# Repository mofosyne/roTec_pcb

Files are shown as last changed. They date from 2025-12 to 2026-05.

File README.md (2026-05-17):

# roTec_pcb

<details>
<summary>Revision 5.4 (Though Hole Version)</summary>

| Front (Through Hole Version) | Back (Through Hole Version) |
|:---|:---|
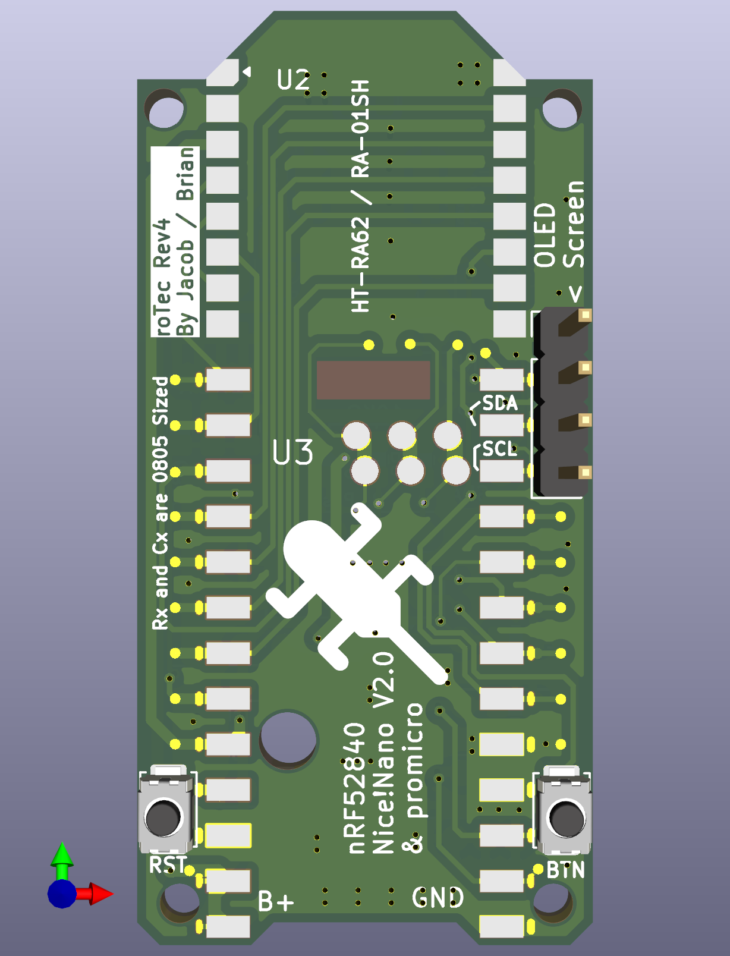
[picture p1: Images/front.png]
Front of PCB
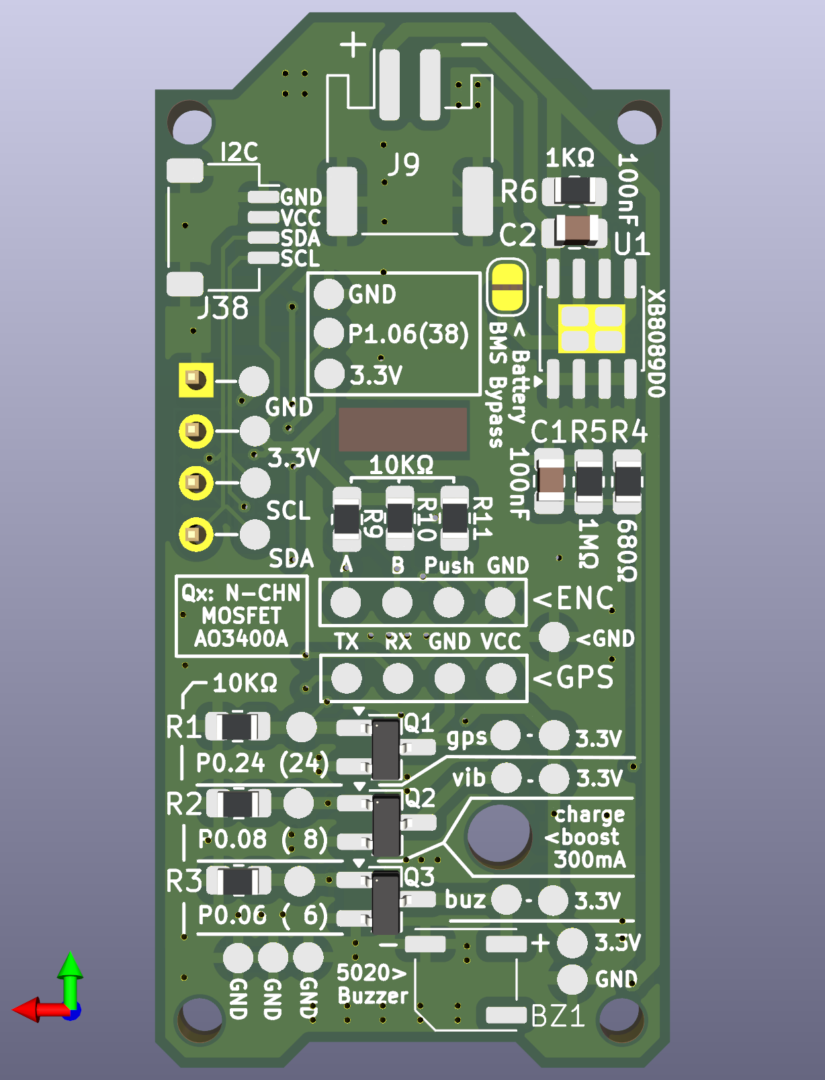
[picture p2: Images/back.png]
Back of PCB
|  |  |

[Release Files For PCB Revision 5.4 (Though Hole Version)](https://github.com/mofosyne/roTec_pcb/releases/tag/rev5.4)

</details>

<details>
<summary>Revision 5.3 (Surface Mount)</summary>

| Front | Back |
|:---|:---|
| Front of PCB | Back of PCB |

[Release Files For PCB Revision 5.3 (All features except for GPS tested) (Recommended)](https://github.com/mofosyne/roTec_pcb/releases/tag/rev5.3)

</details>

RoTec is a low-cost nRF52 device with the form-factor of the Heltec v2, v3, & v4 devices compatible with [Meshtastic](https://meshtastic.org/)®, designed for use with rotary encoders as well as being easy to follow for less technical users.

The history of this design is that it is a fork of [Jacob's](https://github.com/jtljac) fork of the fakeTec.

This design is specifically based off of [Šimon Hořánek's](https://github.com/ShimonHoranek) [fakeTec V5 Rev. B](https://github.com/gargomoma/fakeTec_pcb/issues/24), licensed under [CERN-OHL-P-2.0](https://choosealicense.com/licenses/cern-ohl-p-2.0/).

**[For more meshtastic/meshcore/lora DIY nodes, do check this list out!](https://github.com/porkcube/meshtastic-diy-nodes)**

## Design Documentations (Through Hole Version)



* [Schematic as pdf](./Circuit_Through_Hole/documentation/roTec_schematic.pdf)
* [Schematic Bill Of Materials](./Circuit_Through_Hole/documentation/roTec_bom.csv)

* You may also want to manufacture [EC11 Rotary Encoder Horizontal Breakout Board](https://github.com/mofosyne/kicad_useful_pcbs/tree/main?tab=readme-ov-file#ec11-horizontal-breakout-board), so you can more easily wire the rotary encoder to the roTec via a JST-SH-4 cable.

This has the same parts list as the SMD version, but with a few parts subtracted.

## Design Documentations (Surface Mount Version)



* [Schematic as pdf](./Circuit/documentation/roTec_schematic.pdf)
* [Schematic Bill Of Materials](./Circuit/documentation/roTec_bom.csv)

* You may also want to manufacture [EC11 Rotary Encoder Horizontal Breakout Board](https://github.com/mofosyne/kicad_useful_pcbs/tree/main?tab=readme-ov-file#ec11-horizontal-breakout-board), so you can more easily wire the rotary encoder to the roTec via a JST-SH-4 cable.

### Bill of materials

<details>
<summary>Bill of material. For full details and descriptions refer to the csv BOM above instead.</summary>

| Reference | Value | Qty | Manufacturer | MPN | Package | Datasheet | Manufacturer Parts Link (MPL) | Shopping |
|---|---|-----|---|---|---|---|---|---|
| J9 | Molex PicoBlade 0532610271 | 1 | CJT(Changjiang Connectors) | A1251WR-S-2P | SMD,P=1.25mm,Surface Mount,Right Angle | [datasheet](https://www.molex.com/content/dam/molex/molex-dot-com/products/automated/en-us/salesdrawingpdf/532/53261/532610271_sd.pdf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) | [lcsc](https://www.lcsc.com/product-detail/C225111.html) | [LCSC](https://www.lcsc.com/search?q=0532610271&s_z=n_0532610271) |
| U1 | XB8089D0 BMS | 1 | XySemi | XB8089D0 | SOIC-8 | [datasheet](https://www.lcsc.com/datasheet/lcsc_datasheet_2410121637_XySemi-XB8089D0_C2760005.pdf ) | [lcsc](https://www.lcsc.com/product-detail/C2760005.html?s_z=n_XySemi%2520XB8089D0) | [LCSC](https://www.lcsc.com/search?q=XB8089D0&s_z=n_XB8089D0) |
| Q1,Q2,Q3 | n-chn mosfet | 3 | Alpha & Omega Semiconductor Inc. | AO3400A | SOT-23-3L | [datasheet](http://www.aosmd.com/pdfs/datasheet/AO3400A.pdf ) | [lcsc](https://www.lcsc.com/product-detail/C20917.html?s_z=n_AO3400A) | [LCSC](https://www.lcsc.com/search?q=MOSFET%2520N-CH%2520SOT-23-3L&s_z=n_MOSFET%2520N-CH%2520SOT-23-3L) |
| BZ1 | Buzzer 5020 | 1 | HYDZ | HYG-5020A | SMD,5x5mm | [datasheet](https://www.lcsc.com/datasheet/C7544810.pdf ) | [lcsc](https://www.lcsc.com/product-detail/C7544810.html?s_z=n_buzzer%25205020) | [LCSC](https://www.lcsc.com/search?q=Buzzer_5020&s_z=n_Buzzer_5020) |
| J38,J50 | JST-SH-4 | 2 | JST Sales America Inc. | SM04B-SRSS-TB | SMD,P=1mm,Surface Mount,Right Angle | [datasheet](https://www.jst-mfg.com/product/pdf/eng/eSH.pdf ) | [lcsc](https://www.lcsc.com/product-detail/C51940130.html?s_z=n_SM04B-SRSS-TB) | [LCSC](https://www.lcsc.com/search?q=SM04B-SRSS-TB&s_z=n_SM04B-SRSS-TB) |
| OLED1 | I2C OLED Module | 1 | | | Through Hole | [datasheet](https://cdn-shop.adafruit.com/datasheets/SSD1306.pdf ) | [aliexpress](https://www.aliexpress.com/item/1005008738379315.html) | [aliexpress](https://www.aliexpress.com/w/wholesale-0.96-Inch-OLED-Display-Module.html) |
| U3 | nice!nano v2 | 1 | Nice! | nice!nano v2 | nice!nano v2 | [datasheet](https://nicekeyboards.com/docs/nice-nano/pinout-schematic ) | [aliexpress](https://www.aliexpress.com/item/1005010222966695.html) | [aliexpress](https://www.aliexpress.com/w/wholesale-NRF52840-1%2525252d10PCS.html) |
| SW1 | Reset | 1 | XUNPU | TS-1088R-02026 | SMD,4x3mm | [datasheet](https://www.lcsc.com/datasheet/C455280.pdf ) | [lcsc](https://www.lcsc.com/product-detail/C455280.html?s_z=n_TS-1088R-02026) | [LCSC](https://www.lcsc.com/search?q=TS-1088R-02026&s_z=n_TS-1088R-02026) |
| SW2 | SW_Push | 1 | XUNPU | TS-1088R-02026 | SMD,4x3mm | [datasheet](https://www.lcsc.com/datasheet/C455280.pdf ) | [lcsc](https://www.lcsc.com/product-detail/C455280.html?s_z=n_TS-1088R-02026) | [LCSC](https://www.lcsc.com/search?q=TS-1088R-02026&s_z=n_TS-1088R-02026) |
| R1,R2,R3,R9,R10,R11 | 10k | 6 | | | 0805 | | | [LCSC](https://www.lcsc.com/search?q=10K%25200805&s_z=n_10K%25200805) |
| R4 | 680K | 1 | | | 0805 | | | [LCSC](https://www.lcsc.com/search?q=680K%25200805&s_z=n_680K%25200805) |
| R5 | 1.0M | 1 | | | 0805 | | | [LCSC](https://www.lcsc.com/search?q=1M%25200805&s_z=n_1M%25200805) |
| R6 | 1k | 1 | | | 0805 | | | [LCSC](https://www.lcsc.com/search?q=1k%25200805&s_z=n_1k%25200805) |
| SW3 | RotaryEncoder_Switch | 1 | Same Sky (Formerly CUI Devices)  | ACZ11BR1E-15KQA1-12C | EC11 | [datasheet](https://www.cuidevices.com/product/resource/acz11.pdf ) | [aliexpress](https://www.aliexpress.com/item/1005010398201852.html) or [digikey](https://www.digikey.com.au/en/products/detail/same-sky-formerly-cui-devices/ACZ11BR1E-15KQA1-12C/1923334) | [aliexpress](https://www.aliexpress.com/w/wholesale-rotary-encoder-EC11-horizontal.html) or [digikey](https://www.digikey.com.au/short/7v5m7j9j) |
| U2 | HT-RA62 | 1 | Heltec | HT-RA62 | HT-RA62 | [datasheet](https://resource.heltec.cn/download/HT-RA62/HT-RA62(Rev1.1).pdf ) | [aliexpress](https://www.aliexpress.com/item/1005005543917617.html) | [aliexpress](https://www.aliexpress.com/w/wholesale-HT%2525252dRA62.html) |
| C1,C2 | 100nF | 2 | | | 0805 | | | [LCSC](https://www.lcsc.com/search?q=100nF%25200805&s_z=n_100nF%25200805) |
| M1 | ERM Motor | 1 | Seeed Technology Co., Ltd | 316040001 | Wire Leads | [datasheet](https://mm.digikey.com/Volume0/opasdata/d220001/medias/docus/2234/1020-15-003-001_Spec.pdf ) | [digikey](https://www.digikey.com.au/en/products/detail/seeed-technology-co-ltd/316040001/5487672) | [aliexpress](https://www.digikey.com.au/short/332zpfdb) |

Purchase Tips:
* You can often buy SMD resistor kits in booklets from most places like amazon or aliexpress.
* Both nice!nano and promicro versions are supported
* You can swap the AO3400A n-channel mosfet with other higher current mosfet like SI2312 as long as the pins and packaqe size matches.
* Vibrations motors can be purchased in bulk pretty cheaply in aliexpress, ebay, amazon, etc...
* XB8089D0 BMS can be skipped if your battery have integrated battery protection already
* JST-SH-4 is optional if you want to solder the rotary encoder, gps, or i2c sensors directly onto the solder pads provided on the board instead
* For GPS support you can buy either ATGM336H or GY-GPS6MV2 modules
* Any OLED screen can be used. Pick one that is designed for your case. Often it's an SSD1306 controller based OLED screen.
* Any lora radios seen inside this [reference schematic](https://github.com/meshtastic/firmware/blob/develop/variants/nrf52840/diy/nrf52_promicro_diy_tcxo/Schematic_Pro-micro_Pinouts_2025-12-04.pdf) that fits the footprint and pinout is supported
  - Just like the faketecs you can also use RA-01SH.
* This design supports 3 different battery connectors types
  - Molex Picoblade 2-Pin
    - MPC: Molex, MPN: 0532610271
    - MPC: CJT (Changjiang Connectors), MPN: A1251WR-S-2P
    - Pitch: 1.25mm
    - Used By: HelTec LoRa 32
  - JST PH 2-Pin
    - MPN: S2B-PH-SM4-TB
    - Pitch: 2.00mm 
    - Used By: RAK19007 WisBlock
  - Direct wiring. 
    - e.g. JST-PH-2 but as an external wire like this [aliexpress product](https://www.aliexpress.com/item/1005002564191148.html)

</details>

## Setting Up Device

### Configure

Included in this repository is `roTec_module_config.yaml` which when you run below command will configure the buzzer, vibration motor and encoder.

```
PORT=/dev/ttyACM0 # Set to the serial port of the roTec after flashing
meshtastic --port $PORT --info
meshtastic --port $PORT --configure roTec_module_config.yaml
meshtastic --port $PORT --reboot
```

Alternatively you could manually use the web interface to set the settings using <client.meshtastic.org> as shown below
(No GPS settings it's already enabled by default if the module is installed).

#### Rotary Encoder Settings:

| Settings | Value |
|---|---|
| module_config.cannedMessage.allowInputSource | rotEnc1 |
| module_config.cannedMessage.enabled | true |
| module_config.cannedMessage.inputbrokerEventCcw | RIGHT |
| module_config.cannedMessage.inputbrokerEventCw | LEFT |
| module_config.cannedMessage.inputbrokerEventPress | SELECT  |
| module_config.cannedMessage.inputbrokerPinA | 33 |
| module_config.cannedMessage.inputbrokerPinB | 34 |
| module_config.cannedMessage.inputbrokerPinPress | 39 |
| module_config.cannedMessage.rotary1Enabled | true |

#### Vibration Notification Settings:

| Settings | Value |
|---|---|
| module_config.externalNotification.enabled | true  |
| module_config.externalNotification.alertBell | true  |
| module_config.externalNotification.alertBellVibra | true  |
| module_config.externalNotification.alertMessageVibra | true  |
| module_config.externalNotification.outputVibra | 8 |

#### Buzzer Settings:

**Note you have to override buzzer gpio in config device page**

| Settings | Value |
|---|---|
| config.device.buzzerGpio | 6 |
| module_config.externalNotification.enabled | true |
| module_config.externalNotification.alertBell | true |
| module_config.externalNotification.alertBellBuzzer | true |
| module_config.externalNotification.alertMessageBuzzer | true |
| module_config.externalNotification.outputBuzzer | 6 |
| module_config.externalNotification.usePwm | true |
| ringtone | `24:d=32,o=5,b=565:f6,p,f6,4p,p,f6,p,f6,2p,p,b6,p,b6,p,b6,p,b6,p,b,p,b,p,b,p,b,p,b,p,b,p,b,p,b,1p.,2p.,p` |

## Features
- Small size based on Heltec v3: You can use the same cases!
- Lora with Heltec's HT-RA62
- Uses a [n!cenano](https://nicekeyboards.com/nice-nano/) or 
  [NRF52840 ProMicro](https://github.com/joric/nrfmicro/wiki/Alternatives#supermini-nrf52840l)
- BMS For low voltage cutout to prevent LiPo Overdraining
- Battery level sensing
- JST PH2.0mm connector for batteries
- I2C side ports ready to connect an OLED SSD1306 screen.
- Pads for connecting an encoder for canned messages
- Pads for connecting a serial GPS module
- MOSFETs for switching high current components
  - Using a solder pad jumper, MOSFET 1 can chose between the GPS module ground to enable power saving the GPS module, 
    or a regular pad like MOSFETs 2 & 3.
- 2mm mounting holes

## Modifications from fakeTec V5 Rev. B
- Cleaned up schematic
  - Changed Pins representing sides of MCUs to symbols fully representing said MCU
  - Changed labels to my preferred naming scheme
  - Updated/Cleaned up symbol fields to make each component easier to find
    - MPN: Manufacturer Parts Number
    - MPD: Manufacturer Parts Description
    - MPL: Manufacturer Parts Link
    - Shopping: Link to search pages used to locate parts. Useful for finding alternatives.
- Setup netclasses
- Shifted pads `P1.01`, `P1.02`, and `P1.07` to where I'm pretty sure they're supposed to be
- Removed jumper for BMS
  - I will always install a BMS
- Removed jumper for GPS/FET1 Drain to FET1
  - Only one will be connected at a time, probably no difference if this is permanently connected to both
- Switched mosfets to AO3400A
  - I already have these and they're a drop in replacement
- Changed all resistors and Capacitors to 805 sized
  - I already have all the resistors in this size
- Added pullup resistors to rotary encoder pads
  - These probably support internal pullups, but just to be safe
- Added ground pad to rotary encoder pads
- Changed battery connector to a JST PH-2.0mm
  - Struggled to find JST 1.25 connectors
  - PH-2.0mm are also apparently more reliable
- Removed lots of silkscreen text
  - Don't need values or component names, just component references
  - Most of it was overlapping
- Moved BMS to side
  - Keeps it out the way of the battery connector
- Added a lot more stitching between front and back ground planes
- Removed vias from on top of silkscreen and off of pads
- Attempted to reduce layer crossings
- Added test pads for the nice!nano/promicro to help users to figure out if the pads is correctly soldered down.
- Added connectors recommended by [this hackaday article ](https://hackaday.com/2022/05/04/the-connector-zoo-i2c-ecosystems) for easy attachment for i2c devices. Pads also exposed in case you want to solder the i2c device down.
- Added buzzer pads so that buzzer can be included in a more compact manner.
- Added pads to expose all the GPIO pins in case users want to use the GPIO for other purpose.
- Added additional marking to indicate resistance and capacitor values
- Added BMS bypass in case users are using batteries with integrated protection already

# Variants

(aka firmware files)

| Version | Lora Modules | Official Repo link | Unofficial Repo link |
|:---|:---|:---|:---|
| With TCXO | EByte E22/E220-xxxM-22S/HT-RA62  | <a href="https://github.com/meshtastic/firmware/tree/master/variants/nrf52840/diy/nrf52_promicro_diy_tcxo" target="_blank">Official repo - With TCXO</a> | <a href="https://github.com/mrekin/MeshtasticCustomBoards/tree/main/firmware/variants/nrf52840/diy/promicro_diy_m" target="_blank">With TCXO</a> @mrekin/MeshtasticCustomBoards |
| Without TCXO | EByte E22/E220-xxxMM-22S/RA-01SH | <a href="https://github.com/meshtastic/firmware/tree/master/variants/nrf52840/diy/nrf52_promicro_diy_xtal" target="_blank">Official repo - Without TCXO</a> | <a href="https://github.com/mrekin/MeshtasticCustomBoards/tree/main/firmware/variants/nrf52840/diy/promicro_diy_mm" target="_blank">Without TCXO</a> @mrekin/MeshtasticCustomBoards |

> If you don't want to build your own image use <a href="https://flasher.meshtastic.org/" target="_blank">the official web flasher</a>. Select the `NRF52 Pro-micro DIY` under `Community Supported Devices` as your target device.

# Supported Cases

Refer to [this page](./Cases/README.md) for details on supported cases that this design will fit into.

# About Meshtastic
[Meshtastic](https://meshtastic.org/)® is a registered trademark of Meshtastic LLC. Meshtastic software components are released under various licenses, see github for details.

# Disclaimer
No warranty is provided.
You use it at your own risk and take the responsibility upon yourself.

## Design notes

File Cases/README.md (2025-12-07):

# Cases

This folder is for cases designed specifically for this device.

Typically we would just point you towards an external link, but we may have copies here if modification was required to make this design fit into it.
The license for each of the folder is based on each project's original license unless stated otherwise.

## FaketecMeshtasticCaseWithEncoder_TimurTaipov

This is based off [faketec NRF52 Meshtastic Case With Encoder Buzzer (by Timur Taipov)](https://www.printables.com/model/1102989-faketec-nrf52-meshtastic-case-with-encoderbuzzergp) but it was originally designed for the faketec v4 where the USB type-c port is offset higher due to the header pins.

The folder `FaketecMeshtasticCaseWithEncoder_TimurTaipov` in the repository contains a mostly one to one copy of the original design, except `front.stl` was adapted into `front_faketec_v5.stl` via `front_faketec_v5.scad`.

Inside `front_faketec_v5.stl` it is the same as `front.stl` but with the type-c port shifted upwards to work with this board.

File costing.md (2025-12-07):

# Costings

This is just mostly for figuring out an estimate of cost for this device. It should be in USD.

(FYI was using [this plugin for codium/vscode](https://github.com/mofosyne/vscode-quickcalc) to calculate below costings)

```calc
# 10PCS 503450/523450 3.7V 1000mAh Polymer Lithium Rechargeable Battery Li-ion Battery JST PH2.0- 2P for GPS Smart Phone DVD MP5 
# https://www.aliexpress.com/item/1005005848216887.html
battery = 2.605

# https://www.lcsc.com/product-detail/C455280.html
# SWITCH TACTILE SPST SMD
# XUNPU TS-1088R-02026
button = 0.0373

# https://www.aliexpress.com/item/1005007290608135.html
# EC11 Rotary Encoder
encoder = 0.942

# https://www.aliexpress.com/item/1005010222966695.html
# NRF52840 1-10PCS Pro NRF52840 Development Board Compatible with Nice!Nano V2.0 Bluetooth Charging Management Pro Micro NRF52840
nicenano = 6.199

# https://www.aliexpress.com/item/1005009534289559.html
# Heltec HT-RA62 LoRa Module SX1262
radio = 61.99 / 10
 = 6.199

# JST JST-PH-2 S2B-PH-SM4-TB
battery_connector = 0.1437

# JST JST-SH-4 XY-SM04B-SRSS-TB
i2c_port = 0.046

# AO3400A N-Chn mosfet (SI2312 exist... but is more expensive but can handle higher current)
AO3400A = 0.058

# https://www.lcsc.com/product-detail/C7544810.html
# Buzzer 5020
buzzer = 0.2974

# Batter Protection XB8089D0
XB8089D0 = 0.1223

# capacitors & resistors (Assume... it's all jelly parts... guessed)
passives = 3

total_parts_est = battery + button * 2 + encoder + nicenano + radio + battery_connector + i2c_port + AO3400A + buzzer + XB8089D0 + passives
          = 19.686999999999994

# jlc pcb cost
pcb_cost = (26.20)/30
            = 0.8733333333333333

# 3d printed case (guessed)
case_cost = 2

total_est = total_parts_est + pcb_cost + case_cost
   = 22.56033333333333
```

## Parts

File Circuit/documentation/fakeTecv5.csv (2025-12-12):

Reference | Value | Qty | Manufacturer | MPN | Package | Description | Datasheet | MPD | MPL | Shopping
U1 | XB8089D0 | 1 | XySemi | XB8089D0 | SOIC-8 | 2.9V~6V Lithium-ion/Polymer 1 SOP-8-EP Battery Management ROHS | https://www.lcsc.com/datasheet/lcsc_datasheet_2410121637_XySemi-XB8089D0_C2760005.pdf | One Cell Lithium-ion/Polymer Battery Protection IC | https://www.lcsc.com/product-detail/C2760005.html?s_z=n_XySemi%2520XB8089D0 | https://www.lcsc.com/search?q=XB8089D0&s_z=n_XB8089D0
Q1,Q2,Q3 | AO3400A | 3 | Alpha & Omega Semiconductor Inc. | AO3400A | SOT-23-3L | 30V Vds, 5.7A Id, N-Channel MOSFET, SOT-23 | http://www.aosmd.com/pdfs/datasheet/AO3400A.pdf | 30V 5.7A 48mΩ@2.5V 1.4W SOT-23-3L Single FETs, MOSFETs RoHS | https://www.lcsc.com/product-detail/C20917.html?s_z=n_AO3400A | https://www.lcsc.com/search?q=MOSFET%2520N-CH%2520SOT-23-3L&s_z=n_MOSFET%2520N-CH%2520SOT-23-3L
BZ1 | Buzzer 5020 | 1 | HYDZ | HYG-5020A | SMD,5x5mm | Buzzer, polarized | https://www.lcsc.com/datasheet/C7544810.pdf | 75dB 4kHz 3V SMD,5x5mm Alarms, Buzzers, and Sirens RoHS | https://www.lcsc.com/product-detail/C7544810.html?s_z=n_buzzer%25205020 | https://www.lcsc.com/search?q=Buzzer_5020&s_z=n_Buzzer_5020
J9 | JST-PH-2 | 1 | JST Sales America Inc. | S2B-PH-SM4-TB | SMD,P=2mm,Surface Mount,Right Angle | Generic connectable mounting pin connector, single row, 01x02, script generated (kicad-library-utils/schlib/autogen/connector/) | https://www.jst-mfg.com/product/pdf/eng/ePH.pdf | 2P 1x2P PH Tin -25℃~+85℃ Beige 2mm 100V 2 2A 1 Surface Mount, Right Angle SMD,P=2mm,Surface Mount,Right Angle Headers, Male Pins RoHS | https://www.lcsc.com/product-detail/C295747.html?s_z=n_S2B-PH-SM4-TB | https://www.lcsc.com/search?q=S2B-PH-SM4-TB&s_z=n_S2B-PH-SM4-TB
J38 | JST-SH-4 | 1 | JST Sales America Inc. | SM04B-SRSS-TB | SMD,P=1mm,Surface Mount,Right Angle | Generic connectable mounting pin connector, single row, 01x04, script generated (kicad-library-utils/schlib/autogen/connector/) | https://www.jst-mfg.com/product/pdf/eng/eSH.pdf | 4P 1x4P Tin 1mm 50V 4 1A 1 Surface Mount, Right Angle -25℃~+85℃ SMD,P=1mm,Surface Mount,Right Angle Headers, Male Pins RoHS | https://www.lcsc.com/product-detail/C51940130.html?s_z=n_SM04B-SRSS-TB | https://www.lcsc.com/search?q=SM04B-SRSS-TB&s_z=n_SM04B-SRSS-TB
OLED1 | I2C OLED Module | 1 |  |  | Through Hole | I2C OLED Module With Header pin space 2.54mm | https://cdn-shop.adafruit.com/datasheets/SSD1306.pdf | 0.96 Inch OLED Display Module I2C IIC SPI Serial 128X64 SSD1306 LCD 3.3-5V 4 Pin White/Blue/Yellow Blue for Arduino | https://www.aliexpress.com/item/1005008738379315.html | https://www.aliexpress.com/w/wholesale-0.96-Inch-OLED-Display-Module.html
U3 | nice!nano v2 | 1 | Nice! | nice!nano v2 | nice!nano v2 | NRF52840 Development Board | https://nicekeyboards.com/docs/nice-nano/pinout-schematic | Pro NRF52840 Development Board Compatible with Nice!Nano V2.0 Bluetooth Charging Management Pro Micro NRF52840 | https://www.aliexpress.com/item/1005010222966695.html | https://www.aliexpress.com/w/wholesale-NRF52840-1%2525252d10PCS.html
SW1 | Reset | 1 | XUNPU | TS-1088R-02026 | SMD,4x3mm | Push button switch, generic, two pins | https://www.lcsc.com/datasheet/C455280.pdf | Without Bracket 3.9mm 12V 2.93mm Round Button SPST 50mA SMD,4x3mm Tactile Switches RoHS | https://www.lcsc.com/product-detail/C455280.html?s_z=n_TS-1088R-02026 | https://www.lcsc.com/search?q=TS-1088R-02026&s_z=n_TS-1088R-02026
SW2 | SW_Push | 1 | XUNPU | TS-1088R-02026 | SMD,4x3mm | Push button switch, generic, two pins | https://www.lcsc.com/datasheet/C455280.pdf | Without Bracket 3.9mm 12V 2.93mm Round Button SPST 50mA SMD,4x3mm Tactile Switches RoHS | https://www.lcsc.com/product-detail/C455280.html?s_z=n_TS-1088R-02026 | https://www.lcsc.com/search?q=TS-1088R-02026&s_z=n_TS-1088R-02026
R1,R2,R3,R9,R10,R11 | 10k | 6 |  |  | 0805 | Resistor | ~ |  |  | https://www.lcsc.com/search?q=10K%25200805&s_z=n_10K%25200805
R4 | 680K | 1 |  |  | 0805 | Resistor | ~ |  |  | https://www.lcsc.com/search?q=680K%25200805&s_z=n_680K%25200805
R5 | 1.0M | 1 |  |  | 0805 | Resistor | ~ |  |  | https://www.lcsc.com/search?q=1M%25200805&s_z=n_1M%25200805
R6 | 1k | 1 |  |  | 0805 | Resistor | ~ |  |  | https://www.lcsc.com/search?q=1k%25200805&s_z=n_1k%25200805
SW3 | RotaryEncoder_Switch | 1 | Same Sky (Formerly CUI Devices) | ACZ11BR1E-15KQA1-12C | EC11 | Rotary encoder, dual channel, incremental quadrate outputs, with switch | https://www.cuidevices.com/product/resource/acz11.pdf | EC11 horizontal rotary encoder Plum blossom shaft With switch 15/20mm 5PIN 20bit pulse digital potentiometer With knob cap | https://www.aliexpress.com/item/1005010398201852.html or https://www.digikey.com.au/en/products/detail/same-sky-formerly-cui-devices/ACZ11BR1E-15KQA1-12C/1923334 | https://www.aliexpress.com/w/wholesale-rotary-encoder-EC11-horizontal.html or https://www.digikey.com.au/short/7v5m7j9j
U2 | HT-RA62 | 1 | Heltec | HT-RA62 | HT-RA62 | The Heltec LoRa Series Module HT-RA62 was designed and developed by Heltec Automation. | https://resource.heltec.cn/download/HT-RA62/HT-RA62(Rev1.1).pdf | HT-RA62 Module SX1262 Secondary Development Supports LoRaWAN Protocol Heltec | https://www.aliexpress.com/item/1005005543917617.html | https://www.aliexpress.com/w/wholesale-HT%2525252dRA62.html
C1,C2 | 100nF | 2 |  |  | 0805 | Unpolarized capacitor | ~ |  |  | https://www.lcsc.com/search?q=100nF%25200805&s_z=n_100nF%25200805
M1 | ERM Motor | 1 | Seeed Technology Co., Ltd | 316040001 | Wire Leads | VIBRATION ERM MOTOR 3V | https://mm.digikey.com/Volume0/opasdata/d220001/medias/docus/2234/1020-15-003-001_Spec.pdf | DC Motor Vibration, ERM (Haptic) 3VDC | https://www.digikey.com.au/en/products/detail/seeed-technology-co-ltd/316040001/5487672 | https://www.digikey.com.au/short/332zpfdb

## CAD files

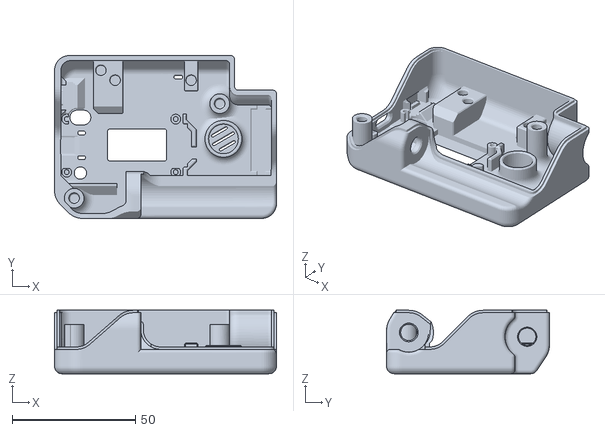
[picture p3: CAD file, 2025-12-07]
Cases/FaketecMeshtasticCaseWithEncoder_TimurTaipov/front_faketec_v5.stl
90.0 x 66.0 x 25.7

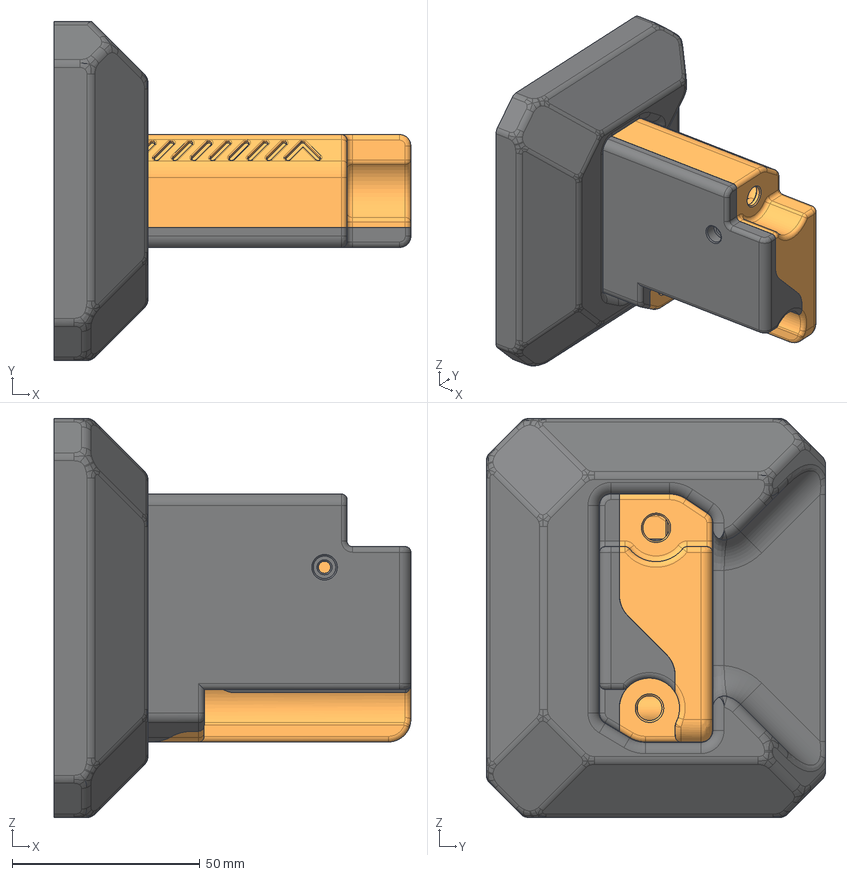
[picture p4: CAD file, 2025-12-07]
Cases/FaketecMeshtasticCaseWithEncoder_TimurTaipov/slabua_meshtasic-case-remix-with-base.step
95.0 x 90.2 x 106.2 mm
FRONT
REAR
BASE

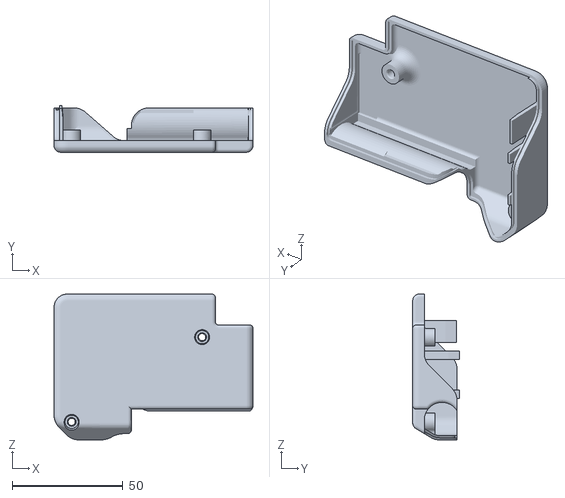
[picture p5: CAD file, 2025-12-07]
Cases/FaketecMeshtasticCaseWithEncoder_TimurTaipov/rear.stl
90.0 x 21.1 x 66.0

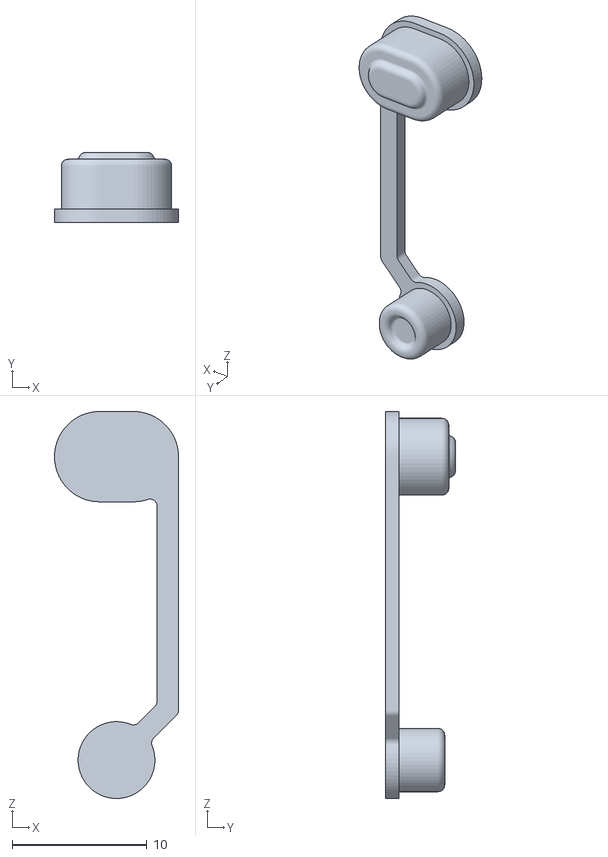
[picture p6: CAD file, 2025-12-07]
Cases/FaketecMeshtasticCaseWithEncoder_TimurTaipov/buttons.stl
9.20 x 5.20 x 28.7

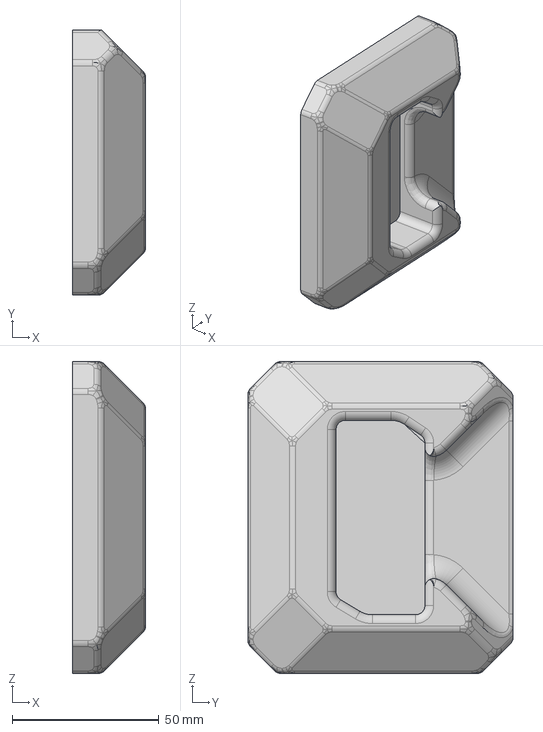
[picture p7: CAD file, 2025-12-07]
Cases/FaketecMeshtasticCaseWithEncoder_TimurTaipov/base.step
25.0 x 90.2 x 106.2 mm

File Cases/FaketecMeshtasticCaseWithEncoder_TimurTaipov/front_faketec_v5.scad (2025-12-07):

// Faketec V5 support
// This will modify a case by shifting the type-c port up to account for the removal of the header pins
// Remix Source: https://www.printables.com/model/1102989-faketec-nrf52-meshtastic-case-with-encoderbuzzergp

$fn = 60;

top_port_enable = true;
bottom_port_remove = true;

// This is the size of the header pin offset
// Dev Note: This is removed after 
header_pin_offset = 2.5;

difference()
{
    union()
    {
        translate([2.8,-12.75,1.95]) 
            rotate([-90,0,0])
                import(file = "front.stl");

        // Plug Bottom Hole
        //if (bottom_port_remove)
        union()
        {
            // Chamfer Front
            hull()
            {
                union()
                {
                    translate([0,5.55/2,0]) 
                        rotate([0,90,0])
                            cylinder(h = 0.5, r1 = 5/2, r2 = (3.5 + 0.4)/2);
                    translate([0,-5.55/2,0]) 
                        rotate([0,90,0])
                            cylinder(h = 0.5, r1 = 5/2, r2 = (3.5 + 0.4)/2);
                }
            }
            // Hole Cutout
            hull()
            {
                union()
                {
                    translate([0,5.55/2,0]) 
                        rotate([0,90,0])
                            cylinder(h = 1.6, r = (3.5 + 0.4)/2);
                    translate([0,-5.55/2,0]) 
                        rotate([0,90,0])
                            cylinder(h = 1.6, r = (3.5 + 0.4)/2);
                }
            }

            // Chamfer Back
            hull()
            {
                union()
                {
                    translate([1.6,5.55/2,0]) 
                        rotate([0,90,0])
                            cylinder(h = 1, r2 = 6/2, r1 = (3.5 + 0.4)/2);
                    translate([1.6,-5.55/2,0]) 
                        rotate([0,90,0])
                            cylinder(h = 1, r2 = 6/2, r1 = (3.5 + 0.4)/2);
                }
            }
        }

    }

    // Cutout
    union()
    {
        union()
        {
            // Chamfer Front
            hull()
            {
                if (top_port_enable)
                translate([-0.01,0,header_pin_offset])
                union()
                {
                    translate([0,6.2/2,0.3]) 
                        rotate([0,90,0])
                            cylinder(h = 0.5, r2 = 3/2, r1 = 4/2);
                    translate([0,-6.2/2,0.3]) 
                        rotate([0,90,0])
                            cylinder(h = 0.5, r2 = 3/2, r1 = 4/2);
                    translate([0,6.2/2,-0.3]) 
                        rotate([0,90,0])
                            cylinder(h = 0.5, r2 = 3/2, r1 = 4/2);
                    translate([0,-6.2/2,-0.3]) 
                        rotate([0,90,0])
                            cylinder(h = 0.5, r2 = 3/2, r1 = 4/2);
                }

                if (!bottom_port_remove)
                translate([-0.01,0,0])
                union()
                {
                    translate([-0.01,5.55/2,0]) 
                        rotate([0,90,0])
                            cylinder(h = 0.5, r1 = 4.7/2, r2 = (3.25 + 0.4)/2);
                    translate([-0.01,-5.55/2,0]) 
                        rotate([0,90,0])
                            cylinder(h = 0.5, r1 = 4.7/2, r2 = (3.25 + 0.4)/2);
                }
            }
            // Chamfer Back
            hull()
            {
                if (top_port_enable)
                translate([0,0,header_pin_offset])
                translate([2,0,0])
                union()
                {
                    translate([0,6.2/2,0.3])
                        rotate([0,90,0])
                            cylinder(h = 0.8, r1 = 3/2, r2 = 5/2);
                    translate([0,-6.2/2,0.3])
                        rotate([0,90,0])
                            cylinder(h = 0.8, r1 = 3/2, r2 = 5/2);
                    translate([0,6.2/2,-0.3])
                        rotate([0,90,0])
                            cylinder(h = 0.8, r1 = 3/2, r2 = 5/2);
                    translate([0,-6.2/2,-0.3])
                        rotate([0,90,0])
                            cylinder(h = 0.8, r1 = 3/2, r2 = 5/2);
                };

                if (!bottom_port_remove)
                translate([0,0,0])
                translate([2,0,0])
                difference()
                {
                    union()
                    {
                        translate([0,6.2/2,0.3])
                            rotate([0,90,0])
                                cylinder(h = 0.8, r1 = 3/2, r2 = 5/2);
                        translate([0,-6.2/2,0.3])
                            rotate([0,90,0])
                                cylinder(h = 0.8, r1 = 3/2, r2 = 5/2);
                        translate([0,6.2/2,-0.3])
                            rotate([0,90,0])
                                cylinder(h = 0.8, r1 = 3/2, r2 = 5/2);
                        translate([0,-6.2/2,-0.3])
                            rotate([0,90,0])
                                cylinder(h = 0.8, r1 = 3/2, r2 = 5/2);
                    }
                    translate([0,0,-2.55]) 
                    cube([3,14,2],center=true);
                }
            }
            // Hole Cutout
            hull()
            {
                if (top_port_enable)
                translate([0,0,header_pin_offset])
                union()
                {
                    translate([0,6.2/2,0.3]) 
                        rotate([0,90,0])
                            cylinder(h = 3, r = 3/2);
                    translate([0,-6.2/2,0.3]) 
                        rotate([0,90,0])
                            cylinder(h = 3, r = 3/2);
                    translate([0,6.2/2,-0.3]) 
                        rotate([0,90,0])
                            cylinder(h = 3, r = 3/2);
                    translate([0,-6.2/2,-0.3]) 
                        rotate([0,90,0])
                            cylinder(h = 3, r = 3/2);
                }
                if (!bottom_port_remove)
                translate([0,0,0])
                union()
                {
                    translate([0,6.2/2,0.3]) 
                        rotate([0,90,0])
                            cylinder(h = 3, r = 3/2);
                    translate([0,-6.2/2,0.3]) 
                        rotate([0,90,0])
                            cylinder(h = 3, r = 3/2);
                    translate([0,6.2/2,-0.3-0.1]) 
                        rotate([0,90,0])
                            cylinder(h = 3, r = 3/2);
                    translate([0,-6.2/2,-0.3-0.1]) 
                        rotate([0,90,0])
                            cylinder(h = 3, r = 3/2);
                }
            }
        }
    }
}

// Main Type-C Hole Model
if (0)
%hull()
{
    union()
    {
        translate([0,6.2/2,0.3]) 
            rotate([0,90,0])
                cylinder(h = 8, r = 3/2);
        translate([0,-6.2/2,0.3]) 
            rotate([0,90,0])
                cylinder(h = 8, r = 3/2);
        translate([0,6.2/2,-0.3]) 
            rotate([0,90,0])
                cylinder(h = 8, r = 3/2);
        translate([0,-6.2/2,-0.3]) 
            rotate([0,90,0])
                cylinder(h = 8, r = 3/2);
    }
}

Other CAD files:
Cases/FaketecMeshtasticCaseWithEncoder_TimurTaipov/front.stl
Cases/FaketecMeshtasticCaseWithEncoder_TimurTaipov/base.stl

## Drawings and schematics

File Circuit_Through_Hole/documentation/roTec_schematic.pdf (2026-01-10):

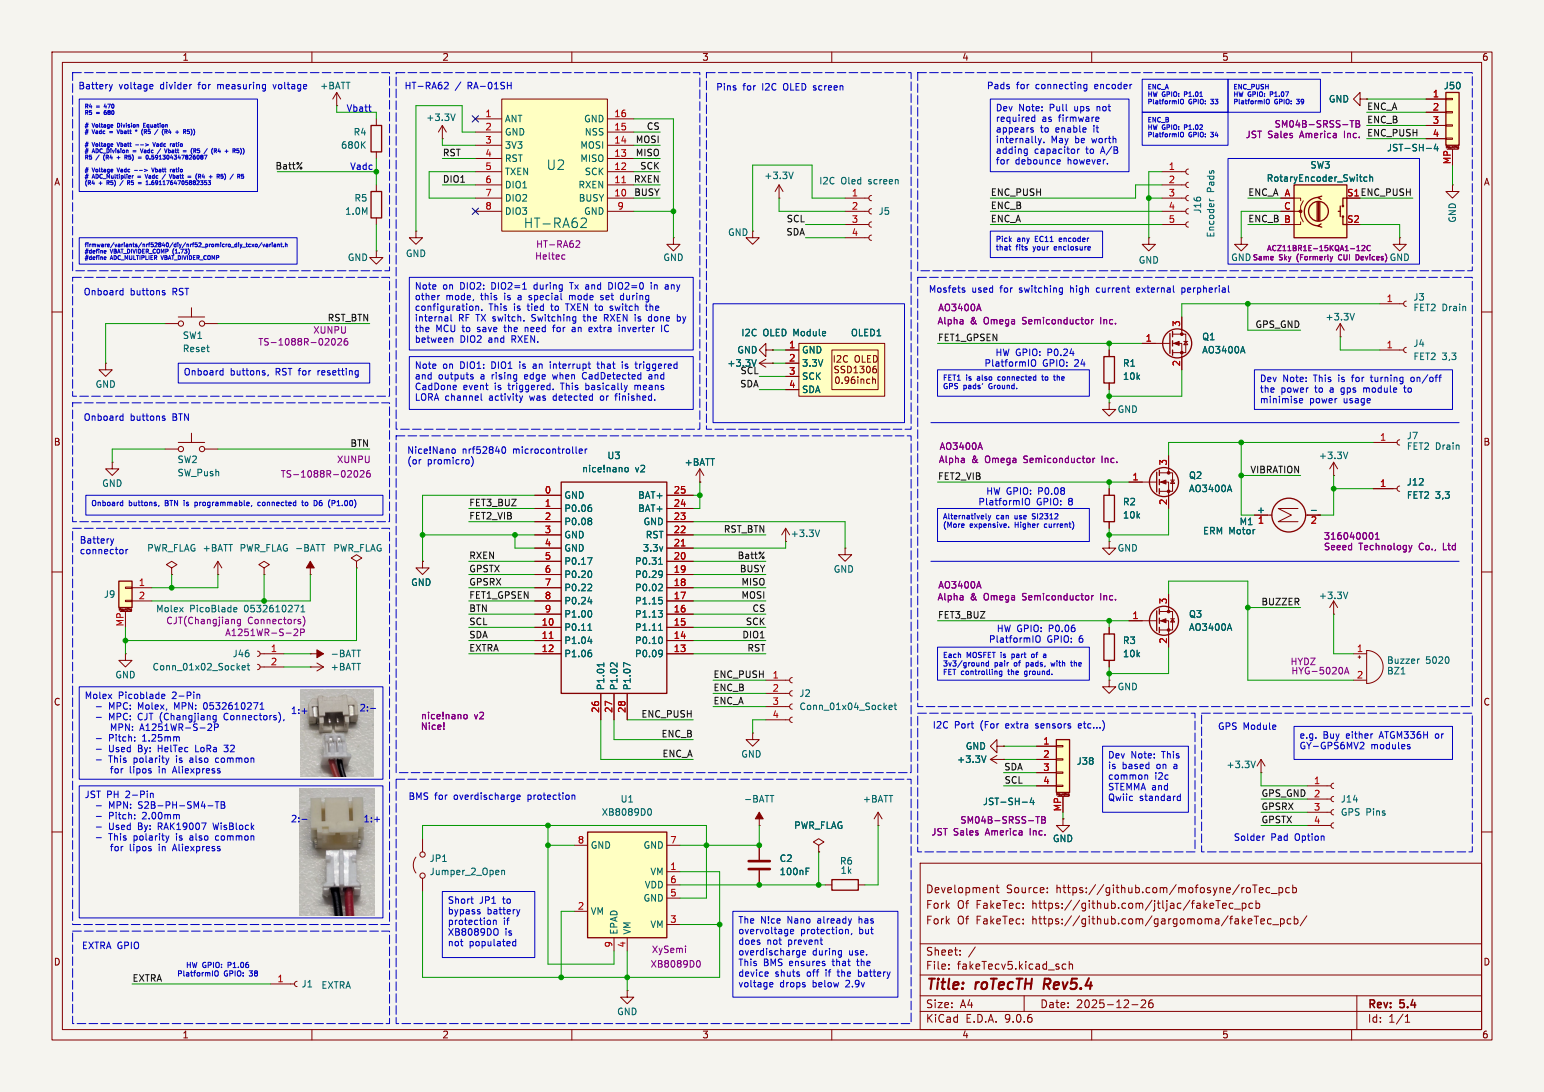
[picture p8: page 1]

JST-SH-4 SM04B-SRSS-TB

appears to enable it

ENC_B GPSRX DIO1 GPSTX RST Batt%

firmware/variants/nrf52840/diy/nrf52_promicro_diy_tcxo/variant.h

Onboard buttons RST Onboard buttons BTN

the MCU to save the need for an extra inverter IC
between DIO2 and RXEN.

3 2 M1 ERM Motor 316040001 Seeed Technology Co., Ltd +

- Pitch: 1.25mm
- Used By: HelTec LoRa 32
for lipos in Aliexpress

JST Sales America Inc.1
JST Sales America Inc. GND

is based on a
common i2c STEMMA and Qwiic standard

4 GND 7 VM 1 VDD 6 GND 5 VM 3 U1 XB8089D0 XB8089D0 XySemi

- MPN: S2B-PH-SM4-TB
- Pitch: 2.00mm
- Used By: RAK19007 WisBlock

device shuts off if the battery
voltage drops below 2.9v

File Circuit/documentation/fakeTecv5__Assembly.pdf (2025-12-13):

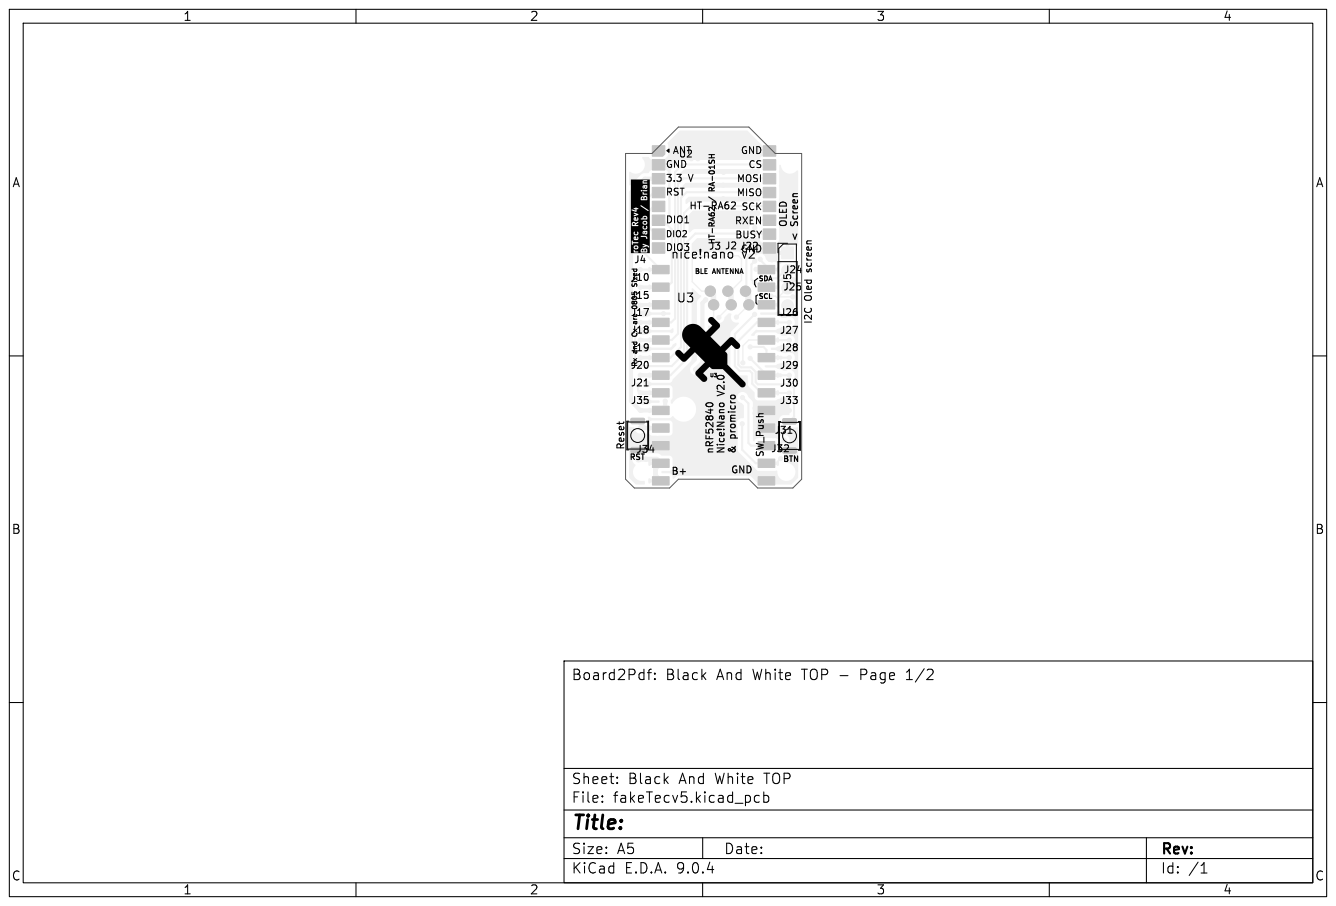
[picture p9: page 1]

OLED < Screen B+ HT-RA62 / RA-01SH
BLE ANTENNA HT-RA62 MISO

# P0.08 ( 8) SCLGND GND

charge <boost 300mA¹⁰⁰nF GND | - | 3.3V + GND

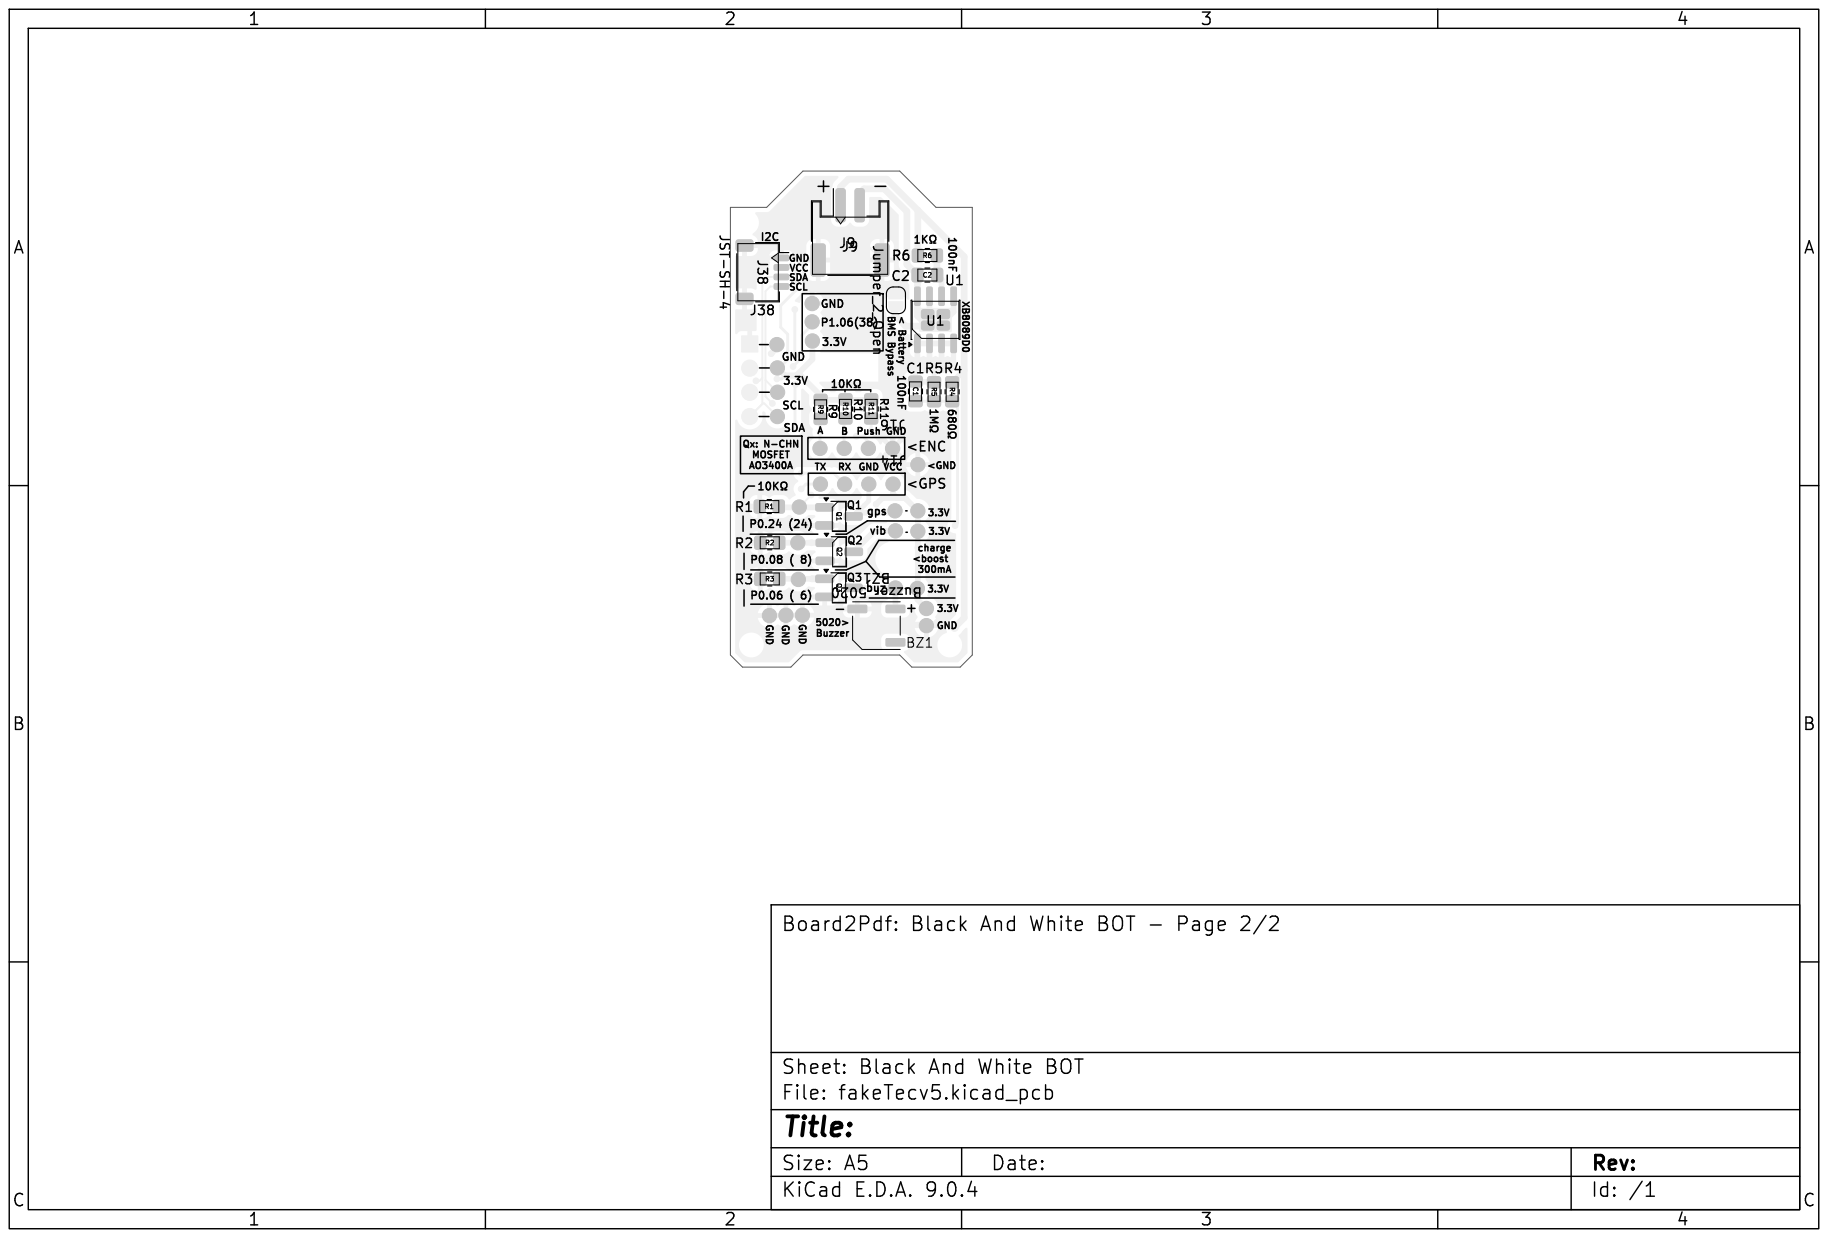
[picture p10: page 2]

VCC< Battery BMS Bypass buz GND
3.3V ¹⁰⁰nF

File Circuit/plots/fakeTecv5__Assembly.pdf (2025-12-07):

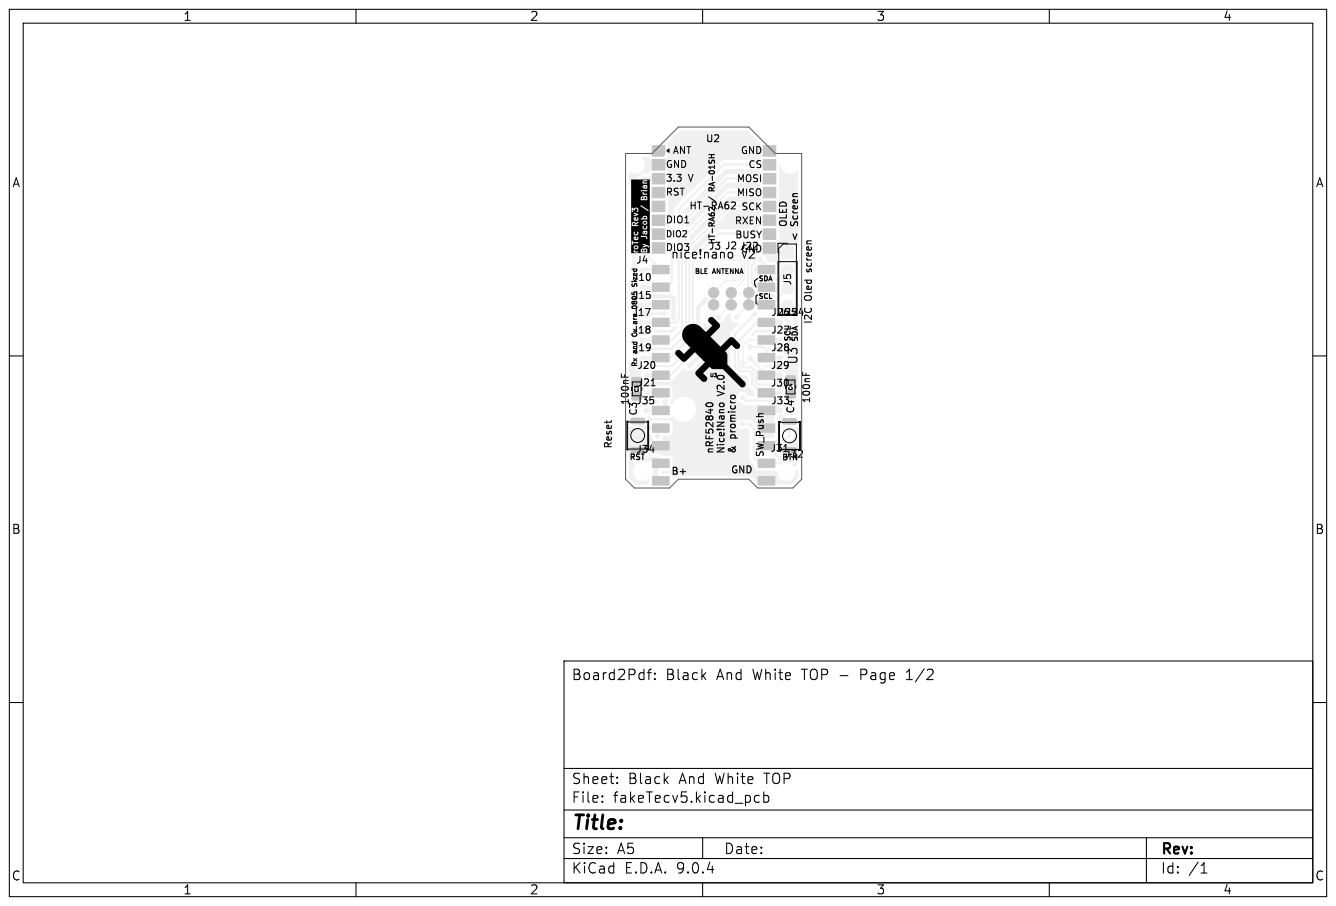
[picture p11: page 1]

OLED < Screen B+ SDA HT-RA62 / RA-01SH
BLE ANTENNA HT-RA62 MISO

# charge <boost 300mA¹⁰⁰nF GND - þÿ10K©

# 3.3V + GND

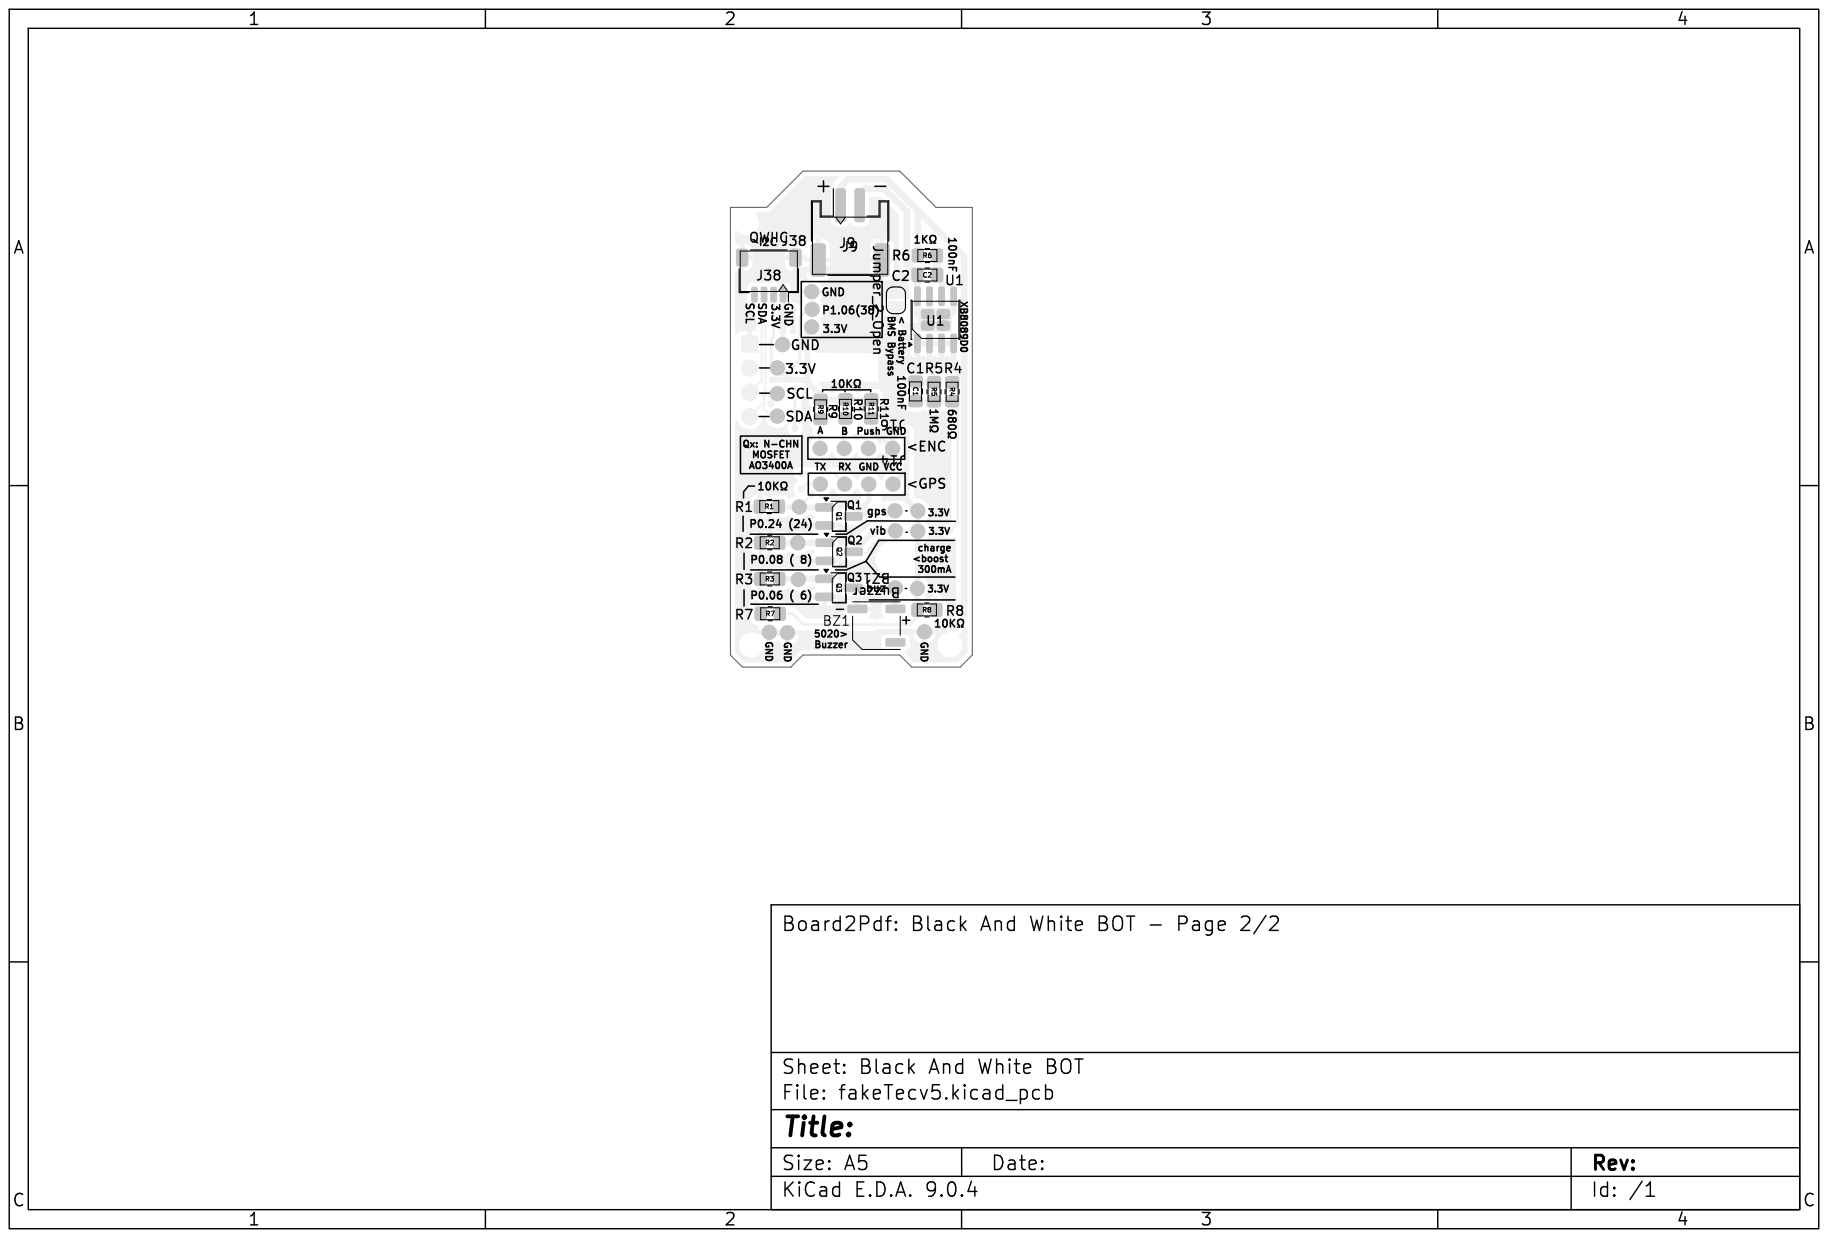
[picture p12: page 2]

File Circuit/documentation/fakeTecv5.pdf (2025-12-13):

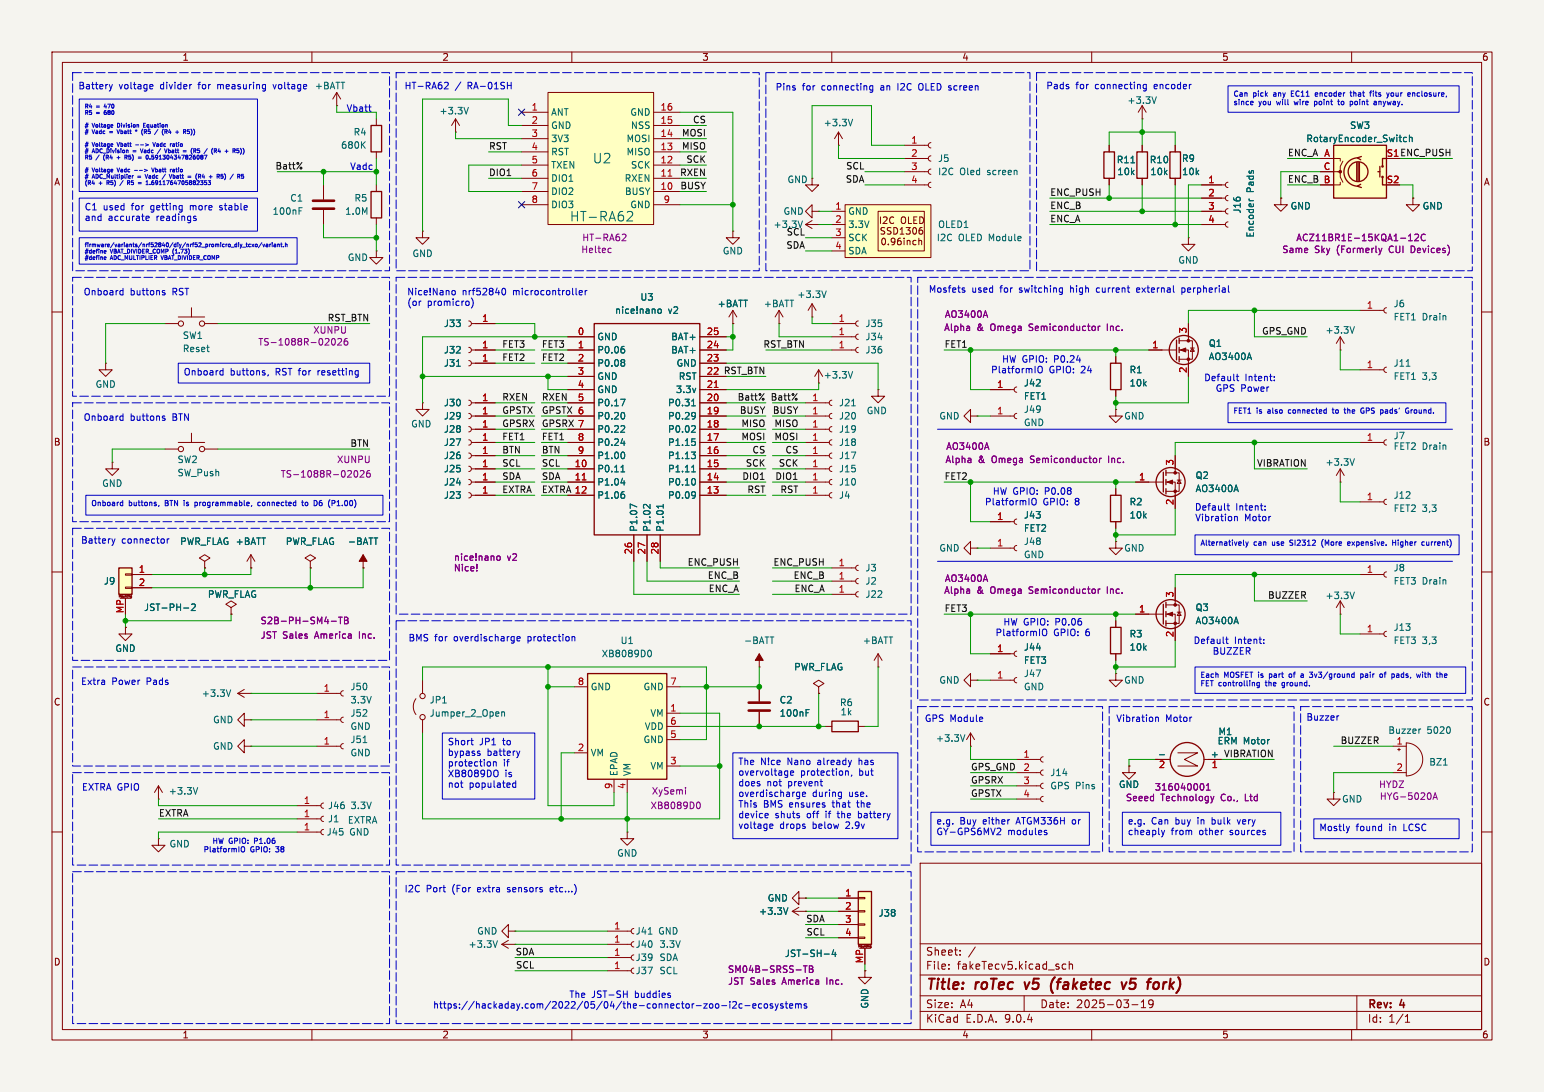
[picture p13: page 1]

Can pick any EC11 encoder that fits your enclosure, since you will wire point to point anyway. C1 used for getting more stable

firmware/variants/nrf52840/diy/nrf52_promicro_diy_tcxo/variant.h

4 GND 7 VM 1 VDD 6 GND 5 VM 3 U1 XB8089D0 XB8089D0 XySemi 1

JST Sales America Inc. 1
2 MP GND

cheaply from other sources Short JP1 to
bypass battery

device shuts off if the battery

I2C Port (For extra sensors etc...)

+3.3V GND

JST-SH-4 SM04B-SRSS-TB

JST Sales America Inc.

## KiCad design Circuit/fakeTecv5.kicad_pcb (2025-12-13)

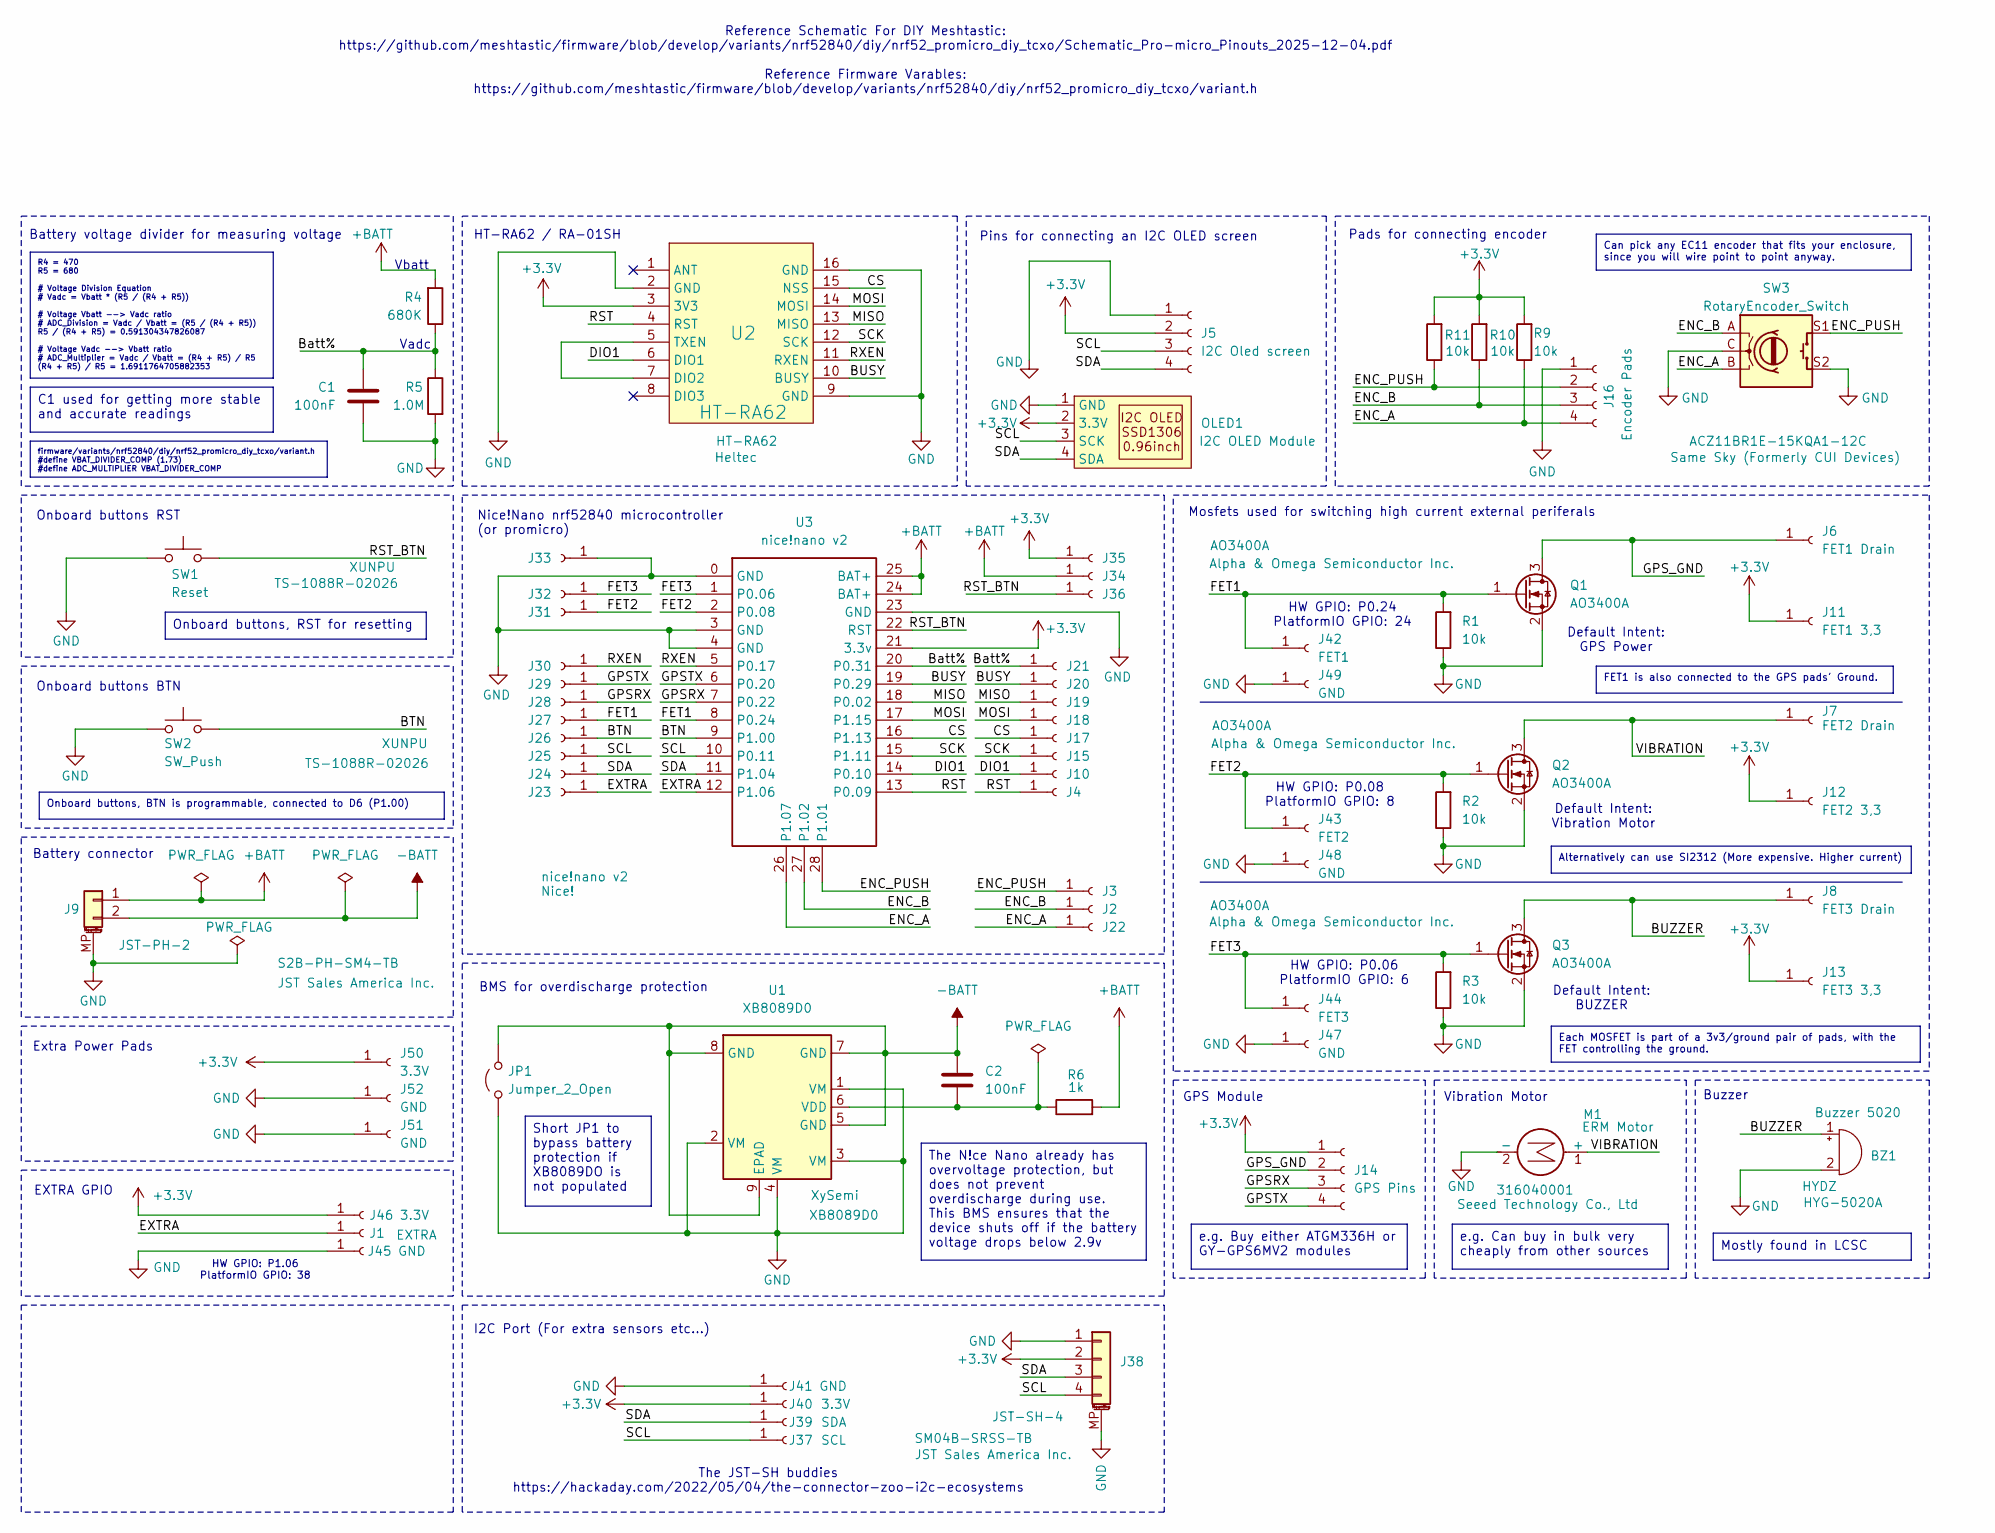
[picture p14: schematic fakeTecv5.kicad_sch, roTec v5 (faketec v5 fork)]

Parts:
BZ1: Buzzer 5020; Buzzer_5020; MPN HYG-5020A
C1, C2: 100nF; C_0805_2012Metric_Pad1.18x1.45mm_HandSolder
J1: EXTRA; SMD_PAD_1x01
J2, J3, J4, J10, J15, J17, J18, J19, J20, J21, J22, J23, J24, J25, J26, J27, J28, J29, J30, J31, J32, J33, J34, J35, J36: TestPoint_Pad_Slim_D0.6mm
J5: I2C Oled screen; PinHeader_1x04_P2.54mm_Vertical; MPN HX PZ2.54-1x4P ZZ
J6: FET1 Drain; SMD_PAD_1x01
J7: FET2 Drain; SMD_PAD_1x01
J8: FET3 Drain; SMD_PAD_1x01
J9: JST-PH-2; JST_PH_S2B-PH-SM4-TB_1x02-1MP_P2.00mm_Horizontal; MPN S2B-PH-SM4-TB
J11: FET1 3,3; SMD_PAD_1x01
J12: FET2 3,3; SMD_PAD_1x01
J13: FET3 3,3; SMD_PAD_1x01
J14: GPS Pins; SMD_PAD_1x04
J16: Encoder Pads; SMD_PAD_1x04
J37: SCL; SMD_PAD_1x01
J38: JST-SH-4; JST_SH_SM04B-SRSS-TB_1x04-1MP_P1.00mm_Horizontal; MPN SM04B-SRSS-TB
J39: SDA; SMD_PAD_1x01
J40, J46, J50: 3.3V; SMD_PAD_1x01
J41, J45, J47, J48, J49, J51, J52: GND; SMD_PAD_1x01
J42: FET1; SMD_PAD_1x01
J43: FET2; SMD_PAD_1x01
J44: FET3; SMD_PAD_1x01
JP1: Jumper_2_Open; SolderJumper-2_P1.3mm_Open_RoundedPad1.0x1.5mm
M1: ERM Motor; MPN 316040001
OLED1: I2C OLED Module
Q1, Q2, Q3: AO3400A; SOT-23_Handsoldering; MPN AO3400A
R1, R2, R3, R9, R10, R11: 10k; R_0805_2012Metric_Pad1.20x1.40mm_HandSolder
R4: 680K; R_0805_2012Metric_Pad1.20x1.40mm_HandSolder
R5: 1.0M; R_0805_2012Metric_Pad1.20x1.40mm_HandSolder
R6: 1k; R_0805_2012Metric_Pad1.20x1.40mm_HandSolder
SW1: Reset; SW_Push_SPST_NO_Alps_SKRK; MPN TS-1088R-02026
SW2: SW_Push; SW_Push_SPST_NO_Alps_SKRK; MPN TS-1088R-02026
SW3: RotaryEncoder_Switch; MPN ACZ11BR1E-15KQA1-12C
U1: XB8089D0; SOIC-8-1EP_3.9x4.9mm_P1.27mm_EP2.41x3.3mm; MPN XB8089D0
U2: HT-RA62; MPN HT-RA62
U3: nice!nano v2; NICE!NANO and pro-micro V2_2 SMD; MPN nice!nano v2

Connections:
+3.3V: J5.2, J11.1, J12.1, J13.1, J14.1, J35.1, J38.2, J40.1, J46.1, J50.1, OLED1.2 (3.3V), R9.2, R10.2, R11.2, U2.3 (3V3), U3.21 (3.3v)
+BATT: J9.1, J34.1, R4.2, R6.2, U3.24 (BAT+), U3.25 (BAT+)
-BATT: C2.1, J9.2, JP1.2 (B), U1.5 (GND), U1.7 (GND), U1.8 (GND), U1.9 (EPAD)
/BTN: J26.1, SW2.2, U3.9 (P1.00)
/BUSY: J20.1, U2.10 (BUSY), U3.19 (P0.29)
/BUZZER: BZ1.1 (+), J8.1, Q3.3 (D)
/Batt%: C1.1, J21.1, R4.1, R5.1, U3.20 (P0.31)
/CS: J17.1, U2.15 (NSS), U3.16 (P1.13)
/DIO1: J10.1, U2.6 (DIO1), U3.14 (P0.10)
/ENC_A: J16.4, J22.1, R9.1, SW3.B, U3.26 (P1.07)
/ENC_B: J2.1, J16.3, R10.1, SW3.A, U3.27 (P1.02)
/ENC_PUSH: J3.1, J16.2, R11.1, SW3.S1, U3.28 (P1.01)
/EXTRA: J1.1, J23.1, U3.12 (P1.06)
/FET1: J27.1, J42.1, Q1.1 (G), R1.2, U3.8 (P0.24)
/FET2: J31.1, J43.1, Q2.1 (G), R2.2, U3.2 (P0.08)
/FET3: J32.1, J44.1, Q3.1 (G), R3.2, U3.1 (P0.06)
/GPSRX: J14.3, J28.1, U3.7 (P0.22)
/GPSTX: J14.4, J29.1, U3.6 (P0.20)
/GPS_GND: J6.1, J14.2, Q1.3 (D)
/MISO: J19.1, U2.13 (MISO), U3.18 (P0.02)
/MOSI: J18.1, U2.14 (MOSI), U3.17 (P1.15)
/RST: J4.1, U2.4 (RST), U3.13 (P0.09)
/RST_BTN: J36.1, SW1.2, U3.22 (RST)
/RXEN: J30.1, U2.11 (RXEN), U3.5 (P0.17)
/SCK: J15.1, U2.12 (SCK), U3.15 (P1.11)
/SCL: J5.3, J25.1, J37.1, J38.4, OLED1.3 (SCK), U3.10 (P0.11)
/SDA: J5.4, J24.1, J38.3, J39.1, OLED1.4 (SDA), U3.11 (P1.04)
GND: BZ1.2 (-), C1.2, J5.1, J9.MP (MountPin), J16.1, J33.1, J38.1, J38.MP (MountPin), J41.1, J45.1, J47.1, J48.1, J49.1, J51.1, J52.1, JP1.1 (A), M1.2 (-), OLED1.1 (GND), Q1.2 (S), Q2.2 (S), Q3.2 (S), R1.1, R2.1, R3.1, R5.2, SW1.1, SW2.1, SW3.C, SW3.S2, U1.1 (VM), U1.2 (VM), U1.3 (VM), U1.4 (VM), U2.2 (GND), U2.9 (GND), U2.16 (GND), U3.0 (GND), U3.3 (GND), U3.4 (GND), U3.23 (GND)
unnamed: J7.1, M1.1 (+), Q2.3 (D)
unnamed: C2.2, R6.1, U1.6 (VDD)
unnamed: U2.5 (TXEN), U2.7 (DIO2)

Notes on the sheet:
GPS Module
I2C Port (For extra sensors etc...)
Nice!Nano nrf52840 microcontroller (or promicro)
Pads for connecting encoder
Default Intent: GPS Power
Mosfets used for switching high current external periferals
BMS for overdischarge protection
The JST-SH buddies https://hackaday.com/2022/05/04/the-connector-zoo-i2c-ecosystems
Extra Power Pads
Battery voltage divider for measuring voltage
Reference Schematic For DIY Meshtastic: https://github.com/meshtastic/firmware/blob/develop/variants/nrf52840/diy/nrf52_promicro_diy_tcxo/Schematic_Pro-micro_Pinouts_2025-12-04.pdf Reference Firmware Varables: https://github.com/meshtastic/firmware/blob/develop/variants/nrf52840/diy/nrf52_promicro_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
Vibration Motor
HW GPIO: P0.24 PlatformIO GPIO: 24
HW GPIO: P0.06 PlatformIO GPIO: 6
HT-RA62 / RA-01SH
HW GPIO: P1.06 PlatformIO GPIO: 38
Onboard buttons RST
EXTRA GPIO
Battery connector
HW GPIO: P0.08 PlatformIO GPIO: 8
Buzzer
Default Intent: Vibration Motor
Vadc
Vbatt
Onboard buttons BTN
Pins for connecting an I2C OLED screen
Default Intent: BUZZER
FET1 is also connected to the GPS pads' Ground.
Alternatively can use SI2312 (More expensive. Higher current)
Mostly found in LCSC
Onboard buttons, BTN is programmable, connected to D6 (P1.00)
e.g. Buy either ATGM336H or GY-GPS6MV2 modules
Can pick any EC11 encoder that fits your enclosure, since you will wire point to point anyway.
Onboard buttons, RST for resetting
C1 used for getting more stable and accurate readings
e.g. Can buy in bulk very cheaply from other sources
R4 = 470 R5 = 680 # Voltage Division Equation # Vadc = Vbatt * (R5 / (R4 + R5)) # Voltage Vbatt --> Vadc ratio # ADC_Division = Vadc / Vbatt = (R5 / (R4 + R5)) R5 / (R4 + R5) = 0.591304347826087 # Voltage Vadc --> Vbatt ratio # ADC_Multiplier = Vadc / Vbatt = (R4 + R5) / R5 (R4 + R5) / R5 = 1.69117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
Each MOSFET is part of a 3v3/ground pair of pads, with the FET controlling the ground.
The N!ce Nano already has overvoltage protection, but does not prevent overdischarge during use. This BMS ensures that the device shuts off if the battery voltage drops below 2.9v
firmware/variants/nrf52840/diy/nrf52_promicro_diy_tcxo/variant.h #define VBAT_DIVIDER_COMP (1.73) #define ADC_MULTIPLIER VBAT_DIVIDER_COMP

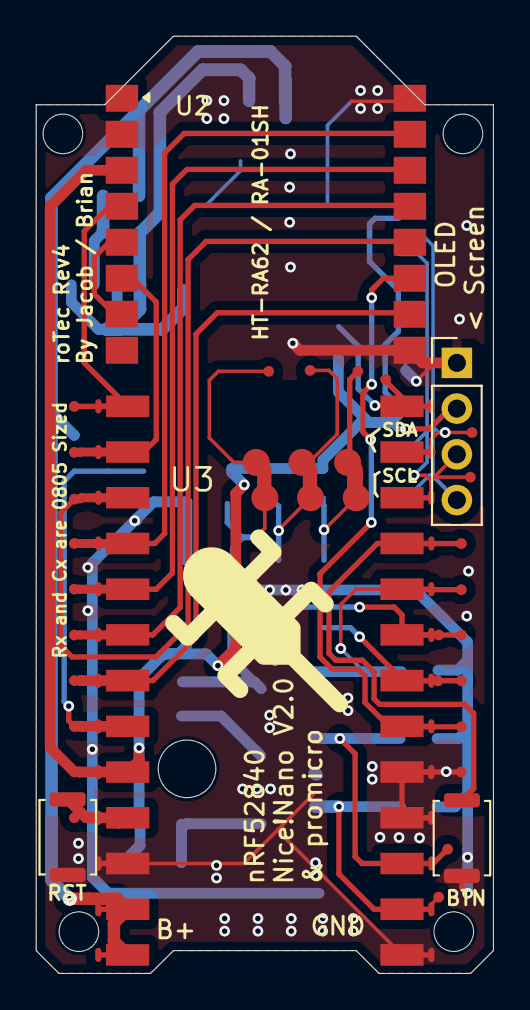
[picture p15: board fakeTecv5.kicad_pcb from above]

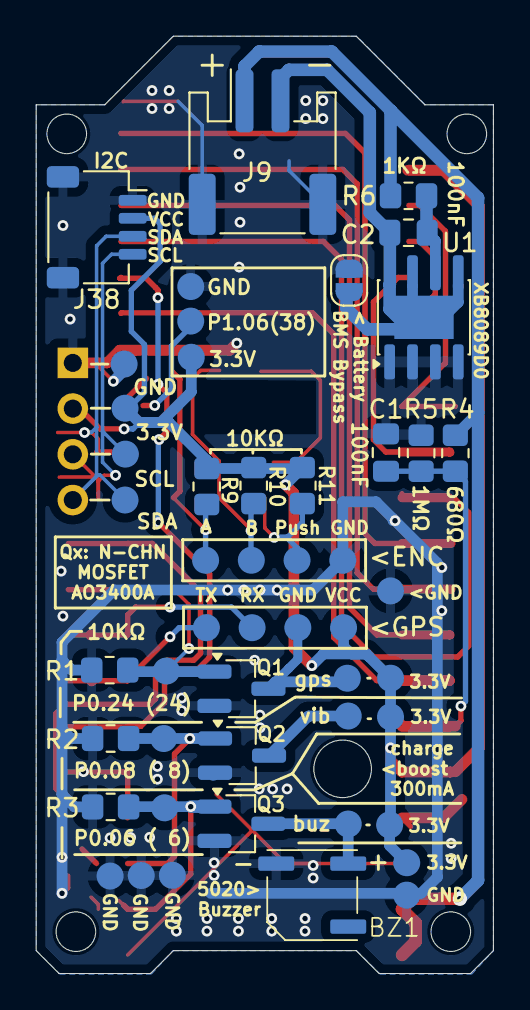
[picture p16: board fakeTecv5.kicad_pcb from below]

Board: 2 copper layers, 25.4 x 52.1 mm, 73 parts (43 on the bottom side), 31 nets.

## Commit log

2025-11-11 Added pull up resistors and ground pad to rotary encoder pads
    [fakeTecv5.kicad_pcb, fakeTecv5.kicad_sch]
2025-12-03 renamed to rotTec and pcb artwork updated
    [fakeTecv5.kicad_pcb, fakeTecv5.kicad_pcb_bom.csv, fakeTecv5.kicad_pcb_positions.csv]
2025-12-04 schematic layout update
    [fakeTecv5.kicad_sch]
2025-12-07 Rename from rotTec_pcb to roTec and pdf and clean up schematic and pcb
    Also add 3D printed case with fixed usb Type-C port position
    [base.step, base.stl, buttons.stl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]
2025-12-07 update bom
    [fakeTecv5.csv, fakeTecv5.kicad_pcb, fakeTecv5.kicad_sch]
2025-12-07 bom shopping link typo
    [fakeTecv5.csv, fakeTecv5.kicad_sch]
2025-12-07 clean up schematic and resolve all schematic design rule checks
    [fakeTecv5.kicad_sch]
2025-12-09 Removed resistor and capacitor for button and also add integrated test pads.
    Also added jlcpcb design rules
    [fakeTecv5.csv, fakeTecv5.kicad_pcb, fakeTecv5.kicad_sch]
2025-12-09 adc multiplier notes adjusted
    [fakeTecv5.kicad_sch]
2025-12-10 improve documentation of battery voltage divider ratio
    [fakeTecv5.kicad_sch]
2025-12-11 bom update and added extra power pads for easier adjustments
    [fakeTecv5.csv, fakeTecv5.kicad_pcb, fakeTecv5.kicad_sch]
2025-12-12 updated bom list and schematic with notes on finding all the parts
    [fakeTecv5.csv, fakeTecv5.kicad_sch]
2025-12-12 background color in schematic
2025-12-12 rotate small i2c connector
    [fakeTecv5.kicad_pcb]
2025-12-13 adjust i2c markings
    [fakeTecv5.kicad_pcb]
2025-12-13 fix schematic typo
    [fakeTecv5.kicad_sch]
2026-01-10 sch: add more dev notes to explain why DIO1 and DIO2 is connected the way they were
    [fakeTecv5.kicad_sch]
